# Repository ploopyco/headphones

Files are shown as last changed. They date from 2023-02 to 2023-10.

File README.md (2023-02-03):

# The Ploopy Headphones

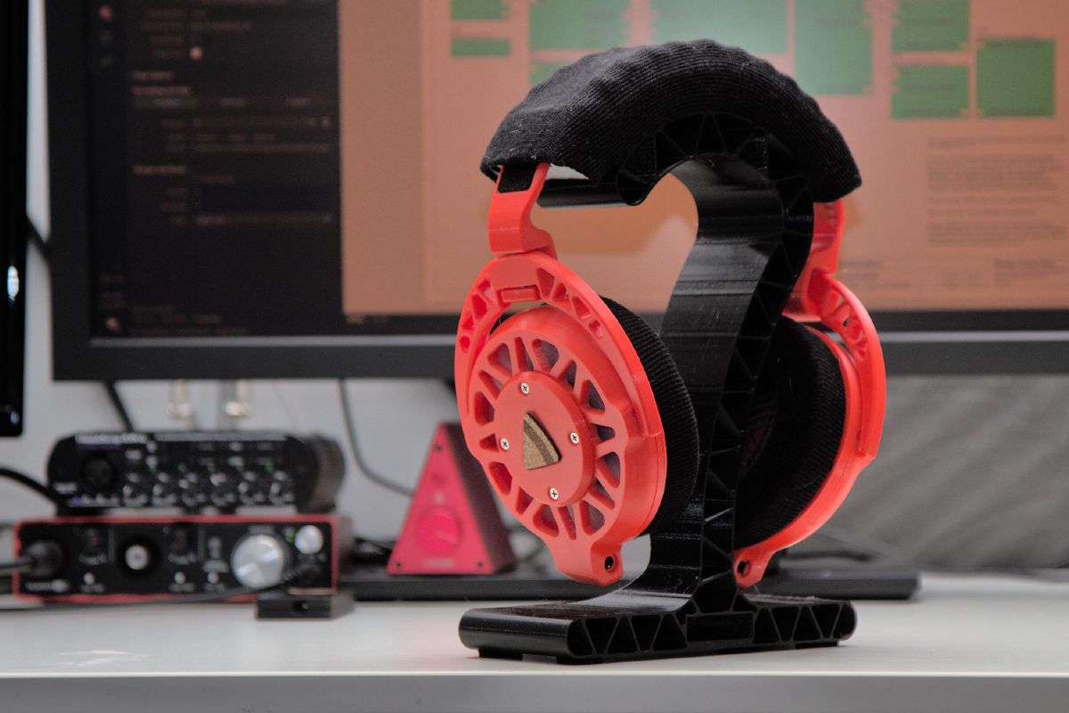
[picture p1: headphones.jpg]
The Ploopy Headphones


By some stroke of luck, you've made your way here. The Ploopy Headphones. Your life will never be the same.

This repository contains all of the design and production files necessary to make a set of Ploopy Headphones. We've also included some kick-ass documentation in the Wiki on how to get it made, assemble it, and program it.

What are you waiting for? Your new life awaits.

## Under what license is this released?

The firmware is released under GPLv3. The hardware is released under OHL CERN v2-S. Check the respective directories for full license text.

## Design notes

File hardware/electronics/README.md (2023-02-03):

"Gould" and "Mazzoleni" are our internal codenames for the boards. You'll also see these names printed on the PCBs, too. These names don't really mean anything; they're just our way of referring to the boards during development, when we don't have release-ready names for things quite yet.

**Gould** -> The Amplifier Board.

**Mazzoleni** -> The Driver Flex Boards.

Simple enough, eh?

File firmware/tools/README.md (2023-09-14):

## filter_test
This is a basic utility for testing the Ploopy headphones filtering routines on a PC.

### Usage
Find a source file and use ffmpeg to convert it to 16bit stereo PCM samples:

```
ffmpeg -i <input file> -vn -f s16le -acodec pcm_s16le input.pcm
```

Run `filter_test` to process the PCM samples. The `filter_test` program takes two arguments an input file and an output file:

```
./filter_test input.pcm output.pcm
```

You can listen to the PCM files using ffplay (which is usually included with ffmpeg):

```
ffplay -f s24le -ar 48000 -ac 2 output.pcm
```

If there are no obvious problems, go ahead and flash your firmware.

## reboot_bootloader.py
If your Ploopy Headphones firmware is new enough, it has support for a USB vendor command that will cause the RP2040 to reboot into the
bootloader. This will enable you to update the firmware without having to remove the case and short the pins on the board.

### Usage
Connect the Ploopy headphones DAC and run:

```
./reboot_bootloader.py
```

You will need python3 and the pyusb module. If you get a permission denied error you may need to configure your udev rules, or run the
script with administrator privileges.

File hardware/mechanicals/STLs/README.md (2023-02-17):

The STLs for the Headphones are packed into a single STL file. This is done for versioning simplicity.

Obviously, the pieces have to be split before they can be printed. Cura and PrusaSlicer both have functionality to split STL files with multiple STLs in them into individual STL pieces. We haven't tested other slicing softwares, and they may also contain this functionality. However, Cura and PrusaSlicer have both been tested and verified as working, and both are available for free.

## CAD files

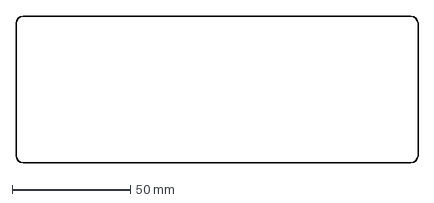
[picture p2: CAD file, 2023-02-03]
hardware/mechanicals/DXFs/HeadbandFoam.DXF
170.0 x 62.0 mm

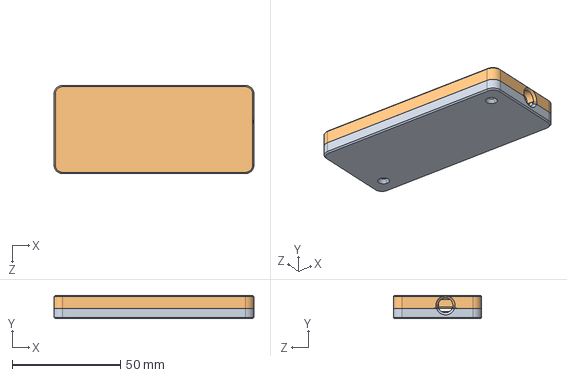
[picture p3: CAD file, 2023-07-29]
hardware/mechanicals/STEPs/DAC-Case-NoLogo.STEP
92.2 x 10.8 x 40.7 mm

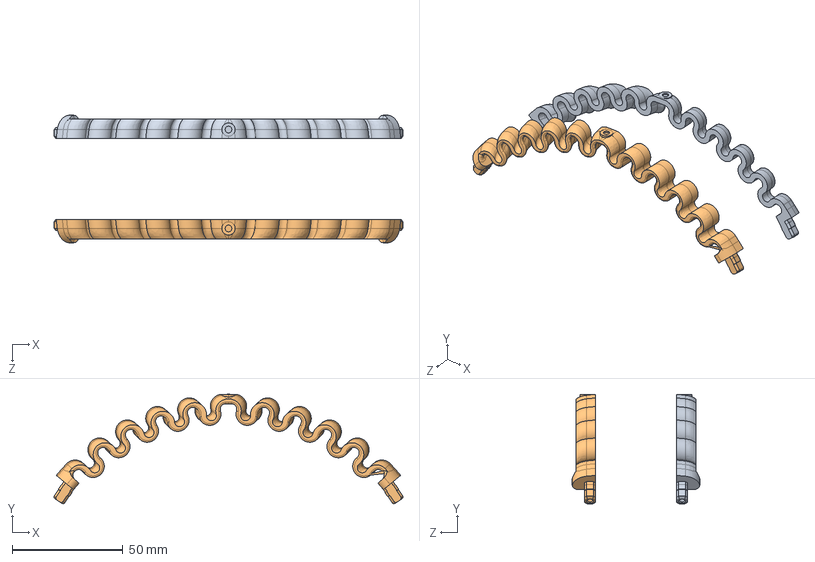
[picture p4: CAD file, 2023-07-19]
hardware/mechanicals/STEPs/Headbands/HPH-038-Headband-Round-LARGE.STEP
157.3 x 49.4 x 57.5 mm

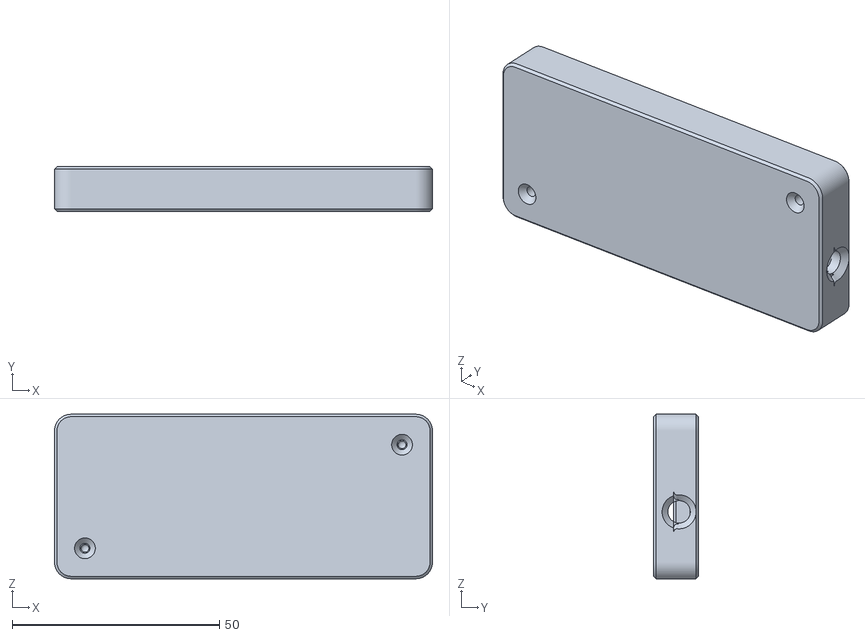
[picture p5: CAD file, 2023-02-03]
hardware/mechanicals/STLs/PloopyPreampCase-RevA.STL
91.2 x 10.8 x 39.7

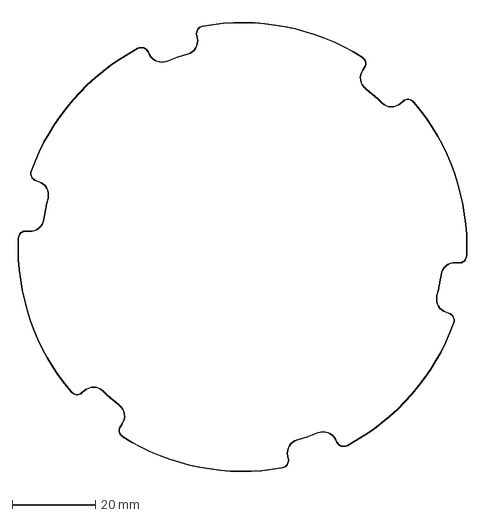
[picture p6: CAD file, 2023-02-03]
hardware/mechanicals/DXFs/Membrane.DXF
109.0 x 111.1 mm

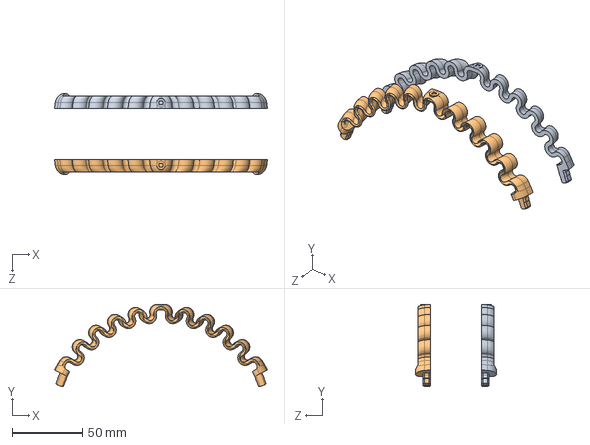
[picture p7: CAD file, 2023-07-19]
hardware/mechanicals/STEPs/Headbands/HPH-040-Headband-Square-MEDIUM.STEP
151.3 x 58.5 x 57.5 mm

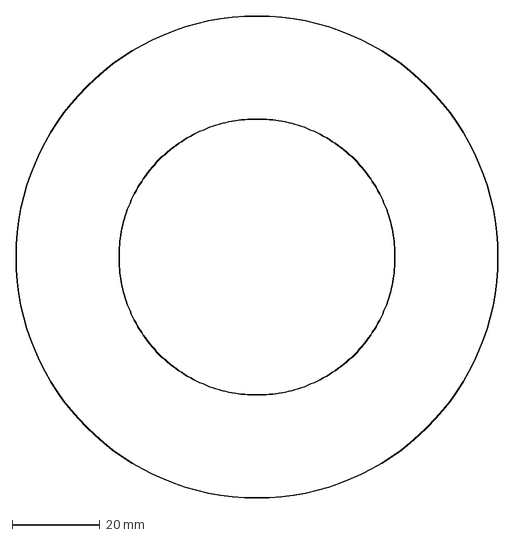
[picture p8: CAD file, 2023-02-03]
hardware/mechanicals/DXFs/Earcup.DXF
110.0 x 110.0 mm

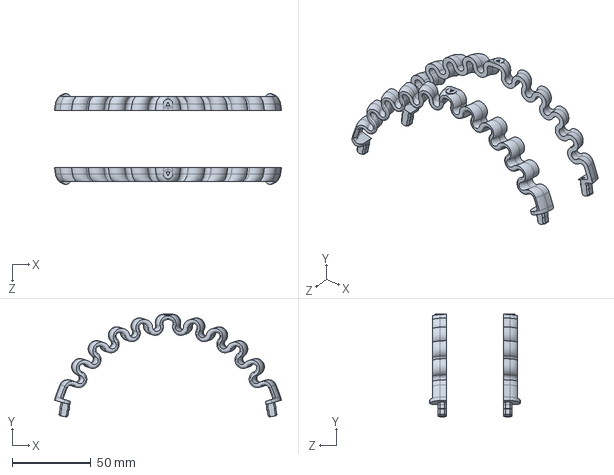
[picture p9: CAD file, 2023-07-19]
hardware/mechanicals/STEPs/Headbands/HPH-041-Headband-Triangle-SMALL.STEP
143.8 x 65.1 x 57.5 mm

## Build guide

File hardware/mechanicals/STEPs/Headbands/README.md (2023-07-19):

There are three sizes of headband, because good things come in threes. The parts can be identified by the mark on the top of the band. For example, the SMALL size of headband has a small triangular mark.

The sizes are relative, and don't correspond to any particular size of head. You might want a small size headband if you have a "small" head, or if you have a "large" head but want a higher clamping force.

For instructions on how to use these headbands, consult the assembly wiki (specifically, Part 4): https://github.com/ploopyco/headphones/wiki/Part-4%3A-Headband

We're always looking for feedback, particularly on ergonomics. If you try all three of these designs and find none of them fit you, please email us at contact@ploopy.co There's a decent chance we can create another size that'll work for you.

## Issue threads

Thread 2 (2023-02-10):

Documentation: Material sourcing improvements

qwertymodo, 2023-02-10:
[Appendix D](https://github.com/ploopyco/headphones/wiki/Appendix-D%3A-Hardware) could use some additional details to properly source materials.

First up, the stockinette only lists a single size, 1.5", but your kits for sale include 2 different sizes, 2" and 3".  So, there's a mismatch there.

Some additional details on the foam would be really helpful, e.g. what kind of material, the density/pressure you use (gives better context to compare against, rather than just "get the lowest possible compression pressure you can find")

Sourcing information for the magnets would be helpful.  I can't seem to find the correct size anywhere.  Even the specialty magnet distributors I've looked at don't seem to carry that exact size.

The rest of the materials seem easy enough to source from the provided information.

megamaniac, 2023-02-10:
I would definitely like to see this as well - for example a 25x5x5 magnet is much easier for me to get hold of. Will this still work in the same way or is 30mm an absolute requirement?

If the dimensional values of the parts can be modified it would be amazing to note this in the descriptions for ease of sourcing.

ploopyco, 2023-02-17:
@qwertymodo I fixed the documentation to include more info about the stockinettes, as well as the foams.

I used Aliexpress to find different magnet sizes and found three vendors supplying magnets in the correct size. Is Aliexpress an option where you are?

@megamaniac The magnet size is not an absolute requirement, of course. The deflection of the PCB is going to change, though, if magnets of different sizes are used.

qwertymodo, 2023-02-17:
AliExpress is definitely an option, and one that I searched before posting here. Unfortunately with things like this it can sometimes be difficult to find exactly what you're looking for, buried in pages of similar items that just slightly aren't correct. Do you happen to have a link to one of those magnet vendors you found?

Closed 2023-07-28.

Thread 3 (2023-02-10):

Option to Purchase Just the PCBs

Wgelyjr, 2023-02-10:
I'd love to manufacture the rest of the parts - it'd be a fun challenge.

I would not like to wrangle a manufacturer into a production run,

I would like to support this awesome project. Mark em up, I don't care, I'll still buy them.

WhosManzIsThis, 2023-02-10:
Agreed,  it would be nice to have an option in between a DIY full kit and sourcing all the parts ourselves.  For example, I happen to have access to 3D printers, but not too many options when it comes to pcb manufacturing, thus having a pre-assembled circuit boards stand-alone purchase option would be ideal.  I really hope the individuals at this company see this thread.

qwertymodo, 2023-02-12:
Bare PCB's only and a "print your own" kit would both be really nice purchase options.  As somebody who has a printer and a lot of really cool filament options, I'd definitely be up for buying a full kit if it didn't feel so wasteful to buy and ship printed parts that I would just throw out.  I was originally thinking of doing a fully self-sourced build, but some of the materials are a bit tricky to find, so a print your own kit would definitely be a good option for people like me.

ploopyco, 2023-02-17:
For the moment, I'm going to continue supplying kits with the 3D-printed parts, only. I do have multiple reasons for sticking with this decision, [which you can read about here](https://blog.ploopy.co/why-we-dont-offer-kits-without-3d-printed-parts-52).

Wgelyjr, 2023-02-18:
I see your reasons, I'm not sure they justify the decision, but it's yours to make. I hope you reconsider at some point, but I bought your kit anyways, and I look forward to receiving it. I appreciate your hard work on this project.

Closed 2023-02-17.

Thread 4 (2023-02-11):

Gerber files

qwertymodo, 2023-02-11:
As far as I can find, Altium doesn't offer any free means of converting their design files into gerbers, would it be possible to include them in the repo?

sirus20x6, 2023-02-14:
to convert altium files into gerbers you have to create an output generator. Then under that output generator file you go to fabrication outputs and you'll want gerber and NC drill files.

qwertymodo, 2023-02-14:
> to convert altium files into gerbers you have to create an output generator. Then under that output generator file you go to fabrication outputs and you'll want gerber and NC drill files.

Yes, but first you have to spend several hundred dollars to purchase Altium. Locking the files behind a proprietary format that has no free way of accessing them isn't really in the spirit of open source.

sirus20x6, 2023-02-14:
I can do it from work tomorrow. I'll also export them as ascii files which
I think can be imported to a few different editors.

On Tue, Feb 14, 2023 at 12:57 PM qwertymodo ***@***.***>
wrote:

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

sirus20x6, 2023-02-15:
[ploopyco.zip](https://github.com/ploopyco/headphones/files/10746818/ploopyco.zip)
Here are the exported gerbers, nc drill files, i also created and included the outjob file and a draftsman file. You'll find exports for ascii versions of the schematics and pcb as well as specctra design, sisoft, p-cad, orcad, ansoft, hyperlynx files.
I've also generated cad files: step, idf, dwg

ploopyco, 2023-02-17:
I believe that KiCAD has an importer for Altium tools.

qwertymodo, 2023-02-17:
I tried a few tools that claimed to support Altium import and they rejected the files because they were not in an ASCII format.

sirus20x6, 2023-02-17:
> I tried a few tools that claimed to support Altium import and they rejected the files because they were not in an ASCII format.

use the zip in my above comment. I have ascii files in there.

Closed 2023-07-28.

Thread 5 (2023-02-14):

unmerge 3d files

sirus20x6, 2023-02-14:
It would really be helpful if every 3d part was in its own file. I'm not sure what we're supposed to do with them all merged together, but I can't give this to my 3d printer

sirus20x6, 2023-02-16:
Been poking at this for a while now. even in the step file everything is fused into one object. you can't actually 3d print it this way.

ploopyco, 2023-02-17:
Cura and PrusaSlicer are two free tools that have both been tested and verified as having the ability to "split" the file into the individual pieces.

As for the STEP file, FreeCAD and Blender are also two free tools that have been tested and verified as having the ability to split the file into the individual components for modification.

sirus20x6, 2023-02-17:
I was unable to split them in either freecad or blender

sirus20x6, 2023-02-17:
I just tried cura. it is unable to split the stl because all the geometry is together under one object. cura is unable to load the stp file

sirus20x6, 2023-02-17:
I just tried prusa slicer as well. it was able to load the stp file, but all the geometry again was under one single object which means it cant be split. it has to be printed as is. in order to print any of these they have to each be their own object which can be done with stp, but is not in this step file.

Closed 2023-02-17.

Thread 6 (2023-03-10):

Is fix16_mul correctly handling the overflow case?

george-norton, 2023-03-10:
I have been browsing the code while I wait for my headphones to arrive, and I can't shake the feeling that something is wrong with the overflow handling here. If I understand right `fix_t` if a 32bit signed value where bit 31 is an overflow bit, bit 30 is the sign bit. This differs from the libfixmath library where there is no separate overflow bit, the sign bit is bit 31. It seems like the shift statement here should be adjusted to shift by 46 bits so the sign bit is included in the test, otherwise if we overflow into the sign bit the overflow will not be detected.

https://github.com/ploopyco/headphones/blob/1771ccab54b087d47403aaec6cd66c3d18addc57/firmware/code/fix16.c#L52

ploopyco, 2023-03-23:
To be perfectly, completely frank, I have no clue. The libfixmath library from which I took the code is not easily decipherable to me. It's entirely possible that you're correct. My only "proof" that I'm right is that the audio sounds right.

If you find that I didn't implement the overflow correction correctly, I'll welcome a pull request.

george-norton, 2023-03-23:
I will have a play when my kit arrives, I wondered if maybe it was the root cause of the audio distortion issues you have been seeing. You seem to have fixed that by reducing the input samples from 16bits to 14bits which could just be making the overflow cases very unlikely or impossible.

I also can't see how the overflow case is handled (although maybe in practice it doesn't happen). It seems like saturating the value would be a good strategy for PCM audio..

george-norton, 2023-03-31:
@ploopyco I have been able to reproduce the audio distortion issue on my PC in a test harness. I have fixed it here:
https://github.com/george-norton/headphones/commit/e6ece89049260f9be8d60c1ed7e397097e602183
But I am reluctant to raise a PR without any real hardware to run it on.

The issue occurs in `bqf_transform` where the value of y can over/underflow causing the sign to flip. With my change `fix16_mul` is allowed to temporarily overflow/underflow as we add and subtract multiple coefficients, the overflow is handled right at the end when we convert back to an `int16_t`.

If you get a chance to test this, and everything works, let me know and I will raise a PR.

george-norton, 2023-03-31:
There is an extra *4 on the volume adjustment in `_as_audio_packet` that might also need to be removed since we are no longer dividing the input samples by 4.

ploopyco, 2023-03-31:
I'll try this on my DAC on Monday. I'm also going to expedite your preorder so that it ships out sooner, so you can try some of this on your own. Really appreciate this sort of contribution; I'll let you know my results on Monday.

ploopyco, 2023-04-03:
It works! Feel free to open a PR, and I'll merge it in.

I've had the privilege of working with some very gifted programmers over my career, but to diagnose and fix a problem at such a low level without actually testing it on the target hardware is one of most incredible feats of engineering I've seen. Well done.

Closed 2023-04-05.

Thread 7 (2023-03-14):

DAC always resampling to 48kHz 16bit

thejevans, 2023-03-14:
I just built my ploopy headphones today. Upon testing, it seems that the DAC always resamples audio to 48kHz 16bit. I made sure to update to the pm5 firmware during testing and the problem still exists. I've tested with sample rates above and below 48kHz and the result is always the same. I tested on multiple linux machines with pipewire and with USB Audio Player Pro on Android.

thejevans, 2023-03-14:
I just noticed the sentence on the product page saying that you all decided to force resampling. Are there downsides to allowing sample rate switching?

ploopyco, 2023-03-23:
The 48kHz/16-bit rate is set by the USB device descriptor [here](https://github.com/ploopyco/headphones/blob/cca0639485fa7383ba7714f32e0514ca87521c97/firmware/code/run.c#L258). So yes, it always downsamples higher bit-rate audio, but that happens before it even gets to the DAC.

The only downside to doing a higher bit rate is that the EQ will have fewer bands. Since all of the EQ is done in the digital domain, a higher bit rate obviously means more bits, and the EQ is primarily limited by processing power. So, more audio quality means less EQ. That's about the only downside (though it's a major one).

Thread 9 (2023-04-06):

Updated firmware binary? 🙏

13tales, 2023-04-06:
Minor issue: could we get an updated compiled firmware?

I'm keen to try out @george-norton's fix to the firmware to see if it has any bearing at all on the USB audio issues affecting recent Macs.

I've tried building it myself, but I'm thinking there may be an issue with my development environment. The resulting noise from 30cm away demonstrated the timeless pedagogical wisdom of the Ploopy firmware-flashing rhyme.

13tales, 2023-04-06:
*Update:* There are definitely problems with my development environment; I've tried building and flashing an earlier commit of the firmware code, with the same result (ie. no sound besides occasional loud screeching.) Would appreciate any insights folks might have on what might be wrong and how to rectify it.

I have some initial issues convincing CMake to find the correct compiler (`arm-none-eabi-gcc`, as specified by the Raspberry Pi Pico PDF), but once I solve those by editing the CMake cache, everything *appears* to work fine; no errors amongst the build output, and I end up with a `ploopy_headphones.uf2` file in my `/build` folder. Flashing it only leads to unpleasant noises and sorrow, however 😬

One discrepancy I've noticed that seems like it might be relevant is that *my* firmware build seems suspiciously larger than either the current binary in `master` or the alpha build you emailed recently. Both of those were ~90kb, whereas mine is coming out at 161kb.

This is the state of VSCode/CMake when I trigger the build (mode: `[Release]`, compiler: `[GCC 10.3.1 arm-none-eabi]`, target: `[all]`)
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

Here's the build output from VS Code:
```
[main] Building folder: pico
[build] Starting build
[proc] Executing command: /opt/homebrew/bin/cmake --build /Users/tom.armstrong/Workspace/pico/build --config Release --target all -j 10 --
[build] [  2%] Creating directories for 'PioasmBuild'
[build] [  2%] Creating directories for 'ELF2UF2Build'
[build] [  3%] Building ASM object pico-sdk/src/rp2_common/boot_stage2/CMakeFiles/bs2_default.dir/compile_time_choice.S.obj
[build] [  5%] No download step for 'ELF2UF2Build'
[build] [  6%] No download step for 'PioasmBuild'
[build] [  7%] No update step for 'ELF2UF2Build'
[build] [ 10%] No update step for 'PioasmBuild'
[build] [ 10%] No patch step for 'ELF2UF2Build'
[build] [ 11%] Linking ASM executable bs2_default.elf
[build] [ 12%] Performing configure step for 'ELF2UF2Build'
[build] [ 13%] No patch step for 'PioasmBuild'
[build] [ 15%] Performing configure step for 'PioasmBuild'
[build] -- Configuring done (0.0s)
[build] loading initial cache file /Users/tom.armstrong/Workspace/pico/build/pico-sdk/src/rp2_common/pico_cyw43_driver/pioasm/tmp/PioasmBuild-cache-Release.cmake
[build] -- Generating done (0.0s)
[build] -- Build files have been written to: /Users/tom.armstrong/Workspace/pico/build/elf2uf2
[build] -- Configuring done (0.0s)
[build] [ 16%] Performing build step for 'ELF2UF2Build'
[build] -- Generating done (0.0s)
[build] -- Build files have been written to: /Users/tom.armstrong/Workspace/pico/build/pioasm
[build] [ 17%] Performing build step for 'PioasmBuild'
[build] [ 17%] Built target bs2_default
[build] [ 18%] Generating bs2_default.bin
[build] [100%] Built target elf2uf2
[build] [ 20%] No install step for 'ELF2UF2Build'
[build] [ 21%] Generating bs2_default_padded_checksummed.S
[build] [ 22%] Completed 'ELF2UF2Build'
[build] [100%] Built target pioasm
[build] [ 22%] Built target ELF2UF2Build
[build] [ 24%] No install step for 'PioasmBuild'
[build] [ 24%] Built target bs2_default_padded_checksummed_asm
[build] [ 25%] Completed 'PioasmBuild'
[build] [ 25%] Built target PioasmBuild
[build] [ 26%] Generating i2s.pio.h
[build] [ 26%] Built target ploopy_headphones_i2s_pio_h
[build] [ 27%] Building C object CMakeFiles/ploopy_headphones.dir/run.c.obj
[build] [ 29%] Building C object CMakeFiles/ploopy_headphones.dir/ringbuf.c.obj
[build] [ 31%] Building C object CMakeFiles/ploopy_headphones.dir/user.c.obj
[build] [ 32%] Building C object CMakeFiles/ploopy_headphones.dir/Users/tom.armstrong/Workspace/pico/pico-sdk/src/rp2_common/hardware_pio/pio.c.obj
[build] [ 34%] Building C object CMakeFiles/ploopy_headphones.dir/fix16.c.obj
[build] [ 34%] Building C object CMakeFiles/ploopy_headphones.dir/i2s.c.obj
[build] [ 35%] Building C object CMakeFiles/ploopy_headphones.dir/Users/tom.armstrong/Workspace/pico/pico-sdk/src/rp2_common/pico_platform/platform.c.obj
[build] [ 36%] Building C object CMakeFiles/ploopy_headphones.dir/bqf.c.obj
[build] [ 37%] Building C object CMakeFiles/ploopy_headphones.dir/Users/tom.armstrong/Workspace/pico/pico-sdk/src/rp2_common/hardware_claim/claim.c.obj
[build] [ 39%] Building C object CMakeFiles/ploopy_headphones.dir/Users/tom.armstrong/Workspace/pico/pico-sdk/src/rp2_common/hardware_sync/sync.c.obj
[build] [ 40%] Building C object CMakeFiles/ploopy_headphones.dir/Users/tom.armstrong/Workspace/pico/pico-sdk/src/rp2_common/hardware_gpio/gpio.c.obj
[build] [ 41%] Building C object CMakeFiles/ploopy_headphones.dir/Users/tom.armstrong/Workspace/pico/pico-sdk/src/rp2_common/hardware_irq/irq.c.obj
[build] [ 43%] Building ASM object CMakeFiles/ploopy_headphones.dir/Users/tom.armstrong/Workspace/pico/pico-sdk/src/rp2_common/hardware_irq/irq_handler_chain.S.obj
[build] [ 44%] Building C object CMakeFiles/ploopy_headphones.dir/Users/tom.armstrong/Workspace/pico/pico-sdk/src/common/pico_sync/sem.c.obj
[build] [ 45%] Building C object CMakeFiles/ploopy_headphones.dir/Users/tom.armstrong/Workspace/pico/pico-sdk/src/common/pico_sync/lock_core.c.obj
[build] [ 46%] Building C object CMakeFiles/ploopy_headphones.dir/Users/tom.armstrong/Workspace/pico/pico-sdk/src/common/pico_sync/mutex.c.obj
[build] [ 48%] Building C object CMakeFiles/ploopy_headphones.dir/Users/tom.armstrong/Workspace/pico/pico-sdk/src/common/pico_sync/critical_section.c.obj
[build] [ 49%] Building C object CMakeFiles/ploopy_headphones.dir/Users/tom.armstrong/Workspace/pico/pico-sdk/src/common/pico_time/time.c.obj
[build] [ 50%] Building C object CMakeFiles/ploopy_headphones.dir/Users/tom.armstrong/Workspace/pico/pico-sdk/src/common/pico_time/timeout_helper.c.obj
[build] [ 51%] Building C object CMakeFiles/ploopy_headphones.dir/Users/tom.armstrong/Workspace/pico/pico-sdk/src/rp2_common/hardware_timer/timer.c.obj
[build] [ 53%] Building C object CMakeFiles/ploopy_headphones.dir/Users/tom.armstrong/Workspace/pico/pico-sdk/src/common/pico_util/datetime.c.obj
[build] [ 54%] Building C object CMakeFiles/ploopy_headphones.dir/Users/tom.armstrong/Workspace/pico/pico-sdk/src/common/pico_util/pheap.c.obj
[build] [ 55%] Building C object CMakeFiles/ploopy_headphones.dir/Users/tom.armstrong/Workspace/pico/pico-sdk/src/common/pico_util/queue.c.obj
[build] [ 56%] Building C object CMakeFiles/ploopy_headphones.dir/Users/tom.armstrong/Workspace/pico/pico-sdk/src/rp2_common/hardware_clocks/clocks.c.obj
[build] [ 58%] Building C object CMakeFiles/ploopy_headphones.dir/Users/tom.armstrong/Workspace/pico/pico-sdk/src/rp2_common/hardware_pll/pll.c.obj
[build] [ 60%] Building C object CMakeFiles/ploopy_headphones.dir/Users/tom.armstrong/Workspace/pico/pico-sdk/src/rp2_common/hardware_watchdog/watchdog.c.obj
[build] [ 60%] Building C object CMakeFiles/ploopy_headphones.dir/Users/tom.armstrong/Workspace/pico/pico-sdk/src/rp2_common/hardware_vreg/vreg.c.obj
[build] [ 62%] Building C object CMakeFiles/ploopy_headphones.dir/Users/tom.armstrong/Workspace/pico/pico-sdk/src/rp2_common/hardware_xosc/xosc.c.obj
[build] [ 63%] Building C object CMakeFiles/ploopy_headphones.dir/Users/tom.armstrong/Workspace/pico/pico-sdk/src/rp2_common/hardware_i2c/i2c.c.obj
[build] [ 64%] Building C object CMakeFiles/ploopy_headphones.dir/Users/tom.armstrong/Workspace/pico/pico-sdk/src/rp2_common/hardware_dma/dma.c.obj
[build] [ 65%] Building C object CMakeFiles/ploopy_headphones.dir/Users/tom.armstrong/Workspace/pico/pico-sdk/src/rp2_common/pico_stdlib/stdlib.c.obj
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
13tales, 2023-04-07:
> I have pushed a simple script here that builds everything inside a simple docker container, it should provide a consistent build environment: https://github.com/george-norton/headphones/tree/docker_build_script/firmware/docker

Thanks! Am I missing something; won't it also need to pull in the Pico SDK and Pico Extras?

13tales, 2023-04-07:
@george-norton Very nice! It worked, thanks.

I did find it was necessary to add `RUN git config --global --add safe.directory "*"` to the Dockerfile, or I received an error along the lines of `"fatal: detected dubious ownership in repository"` from Git when it was attempting to fetch the Pico SDK.

Still very curious about why my attempting to build with VS Code was apparently succeeding, but resulting in those broken oversized binaries 🤔

13tales, 2023-04-07:
It's too early to say conclusively whether the firmware change reduces the Mac M1-related USB audio issues.
I've definitely noticed some occurrences of it since flashing the new firmware just now, but it seems like it *might* possibly have reduced the frequency and severity?
Memory consumption seems to be a cause of the issue, and I'm not working today, so don't have quite my usual burden of docker containers, nodeJS processes, and browser tabs open and competing for resources.

It seems plausible that power consumption might be a factor, based on Colin's speculation, and my testing with the only other USB audio device that I have around (the dongle for a Logitech gaming headset, which *doesn't* suffer from the issue). Is this update likely to have reduced the power draw of the Ploopy DAC at all?

13tales, 2023-04-13:
I had a poke around in the MacOS audio settings; both devices accept 16bit 48khz.
I think this is a low-level issue with MacOS and the M1 hardware in particular; the older and *less*-powerful Intel machines don't seem to suffer from it. [Here's one of many threads on the issue](https://developer.apple.com/forums/thread/677383?page=2), if you're interested.

Firmware programming and USB audio are well outside my realm of competence, so I'm not sure what to look for re: audio clocking. I've done my best to inspect both devices using some of the MacOS utilities and try and figure out what's different. The only thing I've spotted so far is that the `bMaxPacketSize0` property differs between them; it's `0x40` for the Ploopy DAC, `0x10` for the Logitech. No idea whether that could be a factor.

The underlying issue obviously rests with Apple, but I am curious if there's a workaround possible within the Ploopy firmware.

I've tried meddling with the ring buffer size within the Ploopy firmware, doubling it to 64kb—I only use these to listen to music, so I don't really care about latency—but it doesn't fix the issue. It *might* have decreased its frequency, but without measurements to back that up, I think it's probably the placebo effect on my part.

george-norton, 2023-04-13:
@ploopyco The docker build script is a bit quick and dirty, but it works and it should ensure everyone produces identical binaries when they checkout a particular revision of the code. Potentially you could also push prebuilt images to some docker repository and speed up the build process.
Once you have had a play with it, let me know if you are still interested in a PR.

13tales, 2023-04-13:
> @13tales I'll update the repo with an updated firmware. I've been lazy with it, but I'll get it done.

@ploopyco I'm happily building away with the Docker script now, but much appreciated, thanks 🙏 Feel free to close this issue.

I doubt I'm the only person who's going to run into the irritating MacOS/M1 issue, and I'm holding out hope that a Mac user who knows what they're doing might be able to figure out a firmware-side workaround for it. Might create another issue thread as a home for discussion about it, if that's okay by you.

ploopyco, 2023-04-14:
> Might create another issue thread as a home for discussion about it, if that's okay by you.

Fine with me.

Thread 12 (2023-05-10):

Left and right channels reversed

mrlinuxfish, 2023-05-10:
The audio output for the left channel is being sent to the right ear cup and vice verses.

Looking at the driver boards, the tip is only connected on the right side and the ring is only connected on the left side. According to convention, the tip is for left / mono audio and the ring is for the right channel.

A workaround can be wearing the headphones backwards, but it is much more elegant to have the cable come out of the correct side of the headphones (this will also reduce strain on the cables)

ploopyco, 2023-10-16:
I'm guessing we've talked about this on Discord/Reddit since, so I'll just close this issue with some notes for future readers:

As of this writing, the headphone drivers are wired *backwards* -- the left driver is connected to the canonically right channel of the TRS jack and vice versa. This is due to the fact that the supplier for our TRS splitter cable secretly reversed the connections, and we didn't think to check beyond verifying that the correct sound came from the correct side.

If you're using a custom cable, you can use the [headphones toolbox](https://github.com/ploopyco/headphones-toolbox/releases) to flip the channels of the output signal.

Closed 2023-10-16.

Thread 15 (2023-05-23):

Firmware PM8 Requires reflash with every unplug

keeb-time, 2023-05-23:
Flashed firmware pm8 and followed the readme. Flashing the firmware works and the amp immediately reboots and is usable. The amp contiues to work great until it gets unplugged. Upon plugging the amp back in it isnt recognized by the system until the firmware is flashed again, then it works great until unplugged and replugged again. I'm unsure why this is as pm7 worked fine. Computer is running windows 11.

ploopyco, 2023-05-25:
Crap. Yes, this is confirmed. It's also an issue with all builds of the pm9 release.

@george-norton Do you have any ideas? I can debug and fix this issue, but I can only start on it by next Wednesday.

george-norton, 2023-05-25:
Does this happen with other operating systems or just Windows 11 (how about windows 10?)? I have been running my own builds which should be equivalent to pm8 and pm9 and I haven't seen any issues, but I don't use Windows all that much.

george-norton, 2023-05-25:
I tried the pm9 binary with my Windows 10 laptop and I wasn't able to reproduce the issue. Not sure what the cause may be, nothing jumps out when looking at the code again.

Could it be some effect due to the increased I2C clock speed?

ploopyco, 2023-05-25:
Hm. It's possible. The DAC not working after it's been unplugged and plugged back in means that the flash memory isn't being successfully accessed. I know that increasing the SPI bus speed causes this problem, but that's because the MCU and the flash chip communicate via SPI. So, increasing the I2C clock speed shouldn't affect that, but it might be affecting something else.

If you can't reproduce the issue, I'll tackle this.

george-norton, 2023-05-25:
It seems more likely that either the ARM core is taking a fault, or the usb stack is stalling the control endpoint due to some error. I don't have a Windows 11 system - are you able to reproduce the issue on a different OS?

keeb-time, 2023-05-26:
I can see if it works on my work mac, testing in a few here.

keeb-time, 2023-05-26:
Can confirm that the problem is the same on my mac, finder even reports that the disc doesnt eject properly. After a plug and replug, the system doesnt see it. This was attempted with pm9.

ploopyco, 2023-05-31:
Okay...strangest thing. I can't reproduce the issue anymore. On two separate computers, across multiple boards.

@keeb-time, can you try deleting the USB descriptors from your Windows machine and trying again? If that doesn't help, I...honestly have no idea what we're going to do, actually.

george-norton, 2023-05-31:
Maybe we could prepare a test build with the I2c clock reverted to 50khz to see if that fixes it for @keeb-time ?

ploopyco, 2023-06-02:
[Got a test build live here](https://github.com/ploopyco/headphones/blob/ploopyco/keeb-time-test/ploopy_headphones-master-50k.uf2). @keeb-time, let me know if it makes a difference.

keeb-time, 2023-06-03:
Thanks for the test build, just flashed it from my windows computer and it rebooted straight into being a sound output device. I think this is good :)

I'll test on my work mac tomorrow, but I'm betting it works there too

keeb-time, 2023-06-06:
is there anything I can do to assist? is there a way to put the amplifier in a debug mode and capture the output?

george-norton, 2023-06-06:
Unfortunately the DAC doesn't have an easily accessible serial port or debug interface, they are on test points rather than a through hole debug header so they are awkward to access without additional hardware. I don't know about logs on Windows, but if you connect to your Mac then run 'dmesg' you should see a few log messages from MacOS. But I suspect there won't be anything too helpful.

Other than that, if you can spare some time, perhaps we can start doing a binary chop on the changes to see what works and what doesn't. I.e. I could produce a firmware image that contains around half the changes that went into pm8, and we can narrow down the problem that way..

keeb-time, 2023-06-06:
Presently Upon booting with the amp plugged in pre-flash:
https://pastebin.com/MafjaPTQ

dmesg after reset and flash:
[  720.640404] usb 3-7: new full-speed USB device number 6 using xhci_hcd
[  720.768229] usb 3-7: New USB device found, idVendor=2e8a, idProduct=0003, bcdDevice= 1.00
[  720.768243] usb 3-7: New USB device strings: Mfr=1, Product=2, SerialNumber=3
[  720.768246] usb 3-7: Product: RP2 Boot
[  720.768249] usb 3-7: Manufacturer: Raspberry Pi
[  720.768252] usb 3-7: SerialNumber: E0C9125B0D9B
[  720.773601] usb-storage 3-7:1.0: USB Mass Storage device detected
[  720.774295] scsi host1: usb-storage 3-7:1.0
[  721.778230] scsi 1:0:0:0: Direct-Access     RPI      RP2              3    PQ: 0 ANSI: 2
[  721.778987] sd 1:0:0:0: Attached scsi generic sg1 type 0
[  721.780196] sd 1:0:0:0: [sdb] 262144 512-byte logical blocks: (134 MB/128 MiB)
[  721.780762] sd 1:0:0:0: [sdb] Write Protect is off
[  721.780772] sd 1:0:0:0: [sdb] Mode Sense: 03 00 00 00
[  721.781383] sd 1:0:0:0: [sdb] No Caching mode page found
[  721.781391] sd 1:0:0:0: [sdb] Assuming drive cache: write through
[  721.788388]  sdb: sdb1
[  721.788760] sd 1:0:0:0: [sdb] Attached SCSI removable disk
[  731.014677] usb 3-7: USB disconnect, device number 6
[  731.015609] device offline error, dev sdb, sector 260 op 0x1:(WRITE) flags 0x100000 phys_seg 1 prio class 2
[  731.015627] Buffer I/O error on dev sdb1, logical block 259, lost async page write
[  731.038610] FAT-fs (sdb1): unable to read boot sector to mark fs as dirty
[  732.169028] usb 3-7: new full-speed USB device number 7 using xhci_hcd
[  732.296451] usb 3-7: New USB device found, idVendor=2e8a, idProduct=fedd, bcdDevice= 2.00
[  732.296463] usb 3-7: New USB device strings: Mfr=1, Product=2, SerialNumber=3
[  732.296468] usb 3-7: Product: Ploopy Headphones
[  732.296471] usb 3-7: Manufacturer: Ploopy Corporation
[  732.296473] usb 3-7: SerialNumber: 000000000001
[  732.351939] usbcore: registered new interface driver snd-usb-audio

Now, I will unplug and replug:
[  833.620774] usb 3-7: USB disconnect, device number 7

that is the only thing that changes, it never re-recognizes the device after the replug. This might be an issue with starting up the usb controller?

I did all this from my windows laptop running a fedora live image, let me know if there's any more information you need. I want this to work right not just for me but for anyone else that runs into this.

ploopyco, 2023-06-12:
@keeb-time Out of curiosity, what happens if you try George's [headphones toolbox build](https://github.com/george-norton/headphones-toolbox)?

keeb-time, 2023-06-18:
Sorry about the delay, work was super busy and I needed a day. I just attempted with that build and can say that it still needs to be reflashed each time I plug it back in in order to stay working. For the record I have an early unit and am flashing it by shorting the two reset pads and then dragging and dropping the file onto it when it shows up as a drive.

keeb-time, 2023-06-18:
Just tried playing with the toolbox software and even using it to tell the amp to reboot into bootloader and then load the files it still doesnt persist through a reboot. Perhaps my unit has bad flash?
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
keeb-time, 2023-06-21:
I've flashed the new version that you made and I can tentatively say that it works. It's survived three unplugs so far. I'm tempted to put the case back on.

keeb-time, 2023-06-21:
And now its back to not starting up properly...not sure why it seems intermittent

keeb-time, 2023-06-23:
Sorry for the multiple comments here, I'd say that whatever you did is an improvement enough that the amp is usable so long as I plug and unplug it enough times. Something is still off but it's an improvement over how it was. I'm curious as to why the firmware's prior to this one work every time. I'm new to the dev world and this has been a good learning experience so far

Roosta078, 2023-06-29:
This seems like the same bug I have experienced and fixed in my [PR](https://github.com/george-norton/headphones/pull/1) from yesterday.  This change completely fixed the issue for me.  To summarize, the SPI flash speed was getting set out of spec for the flash chip.  Perhaps the higher clock speed was fine on some silicon, but not on others.  @keeb-time could you try out that version?

keeb-time, 2023-06-29:
I should be able to flash that later tonight, looking forward to seeing how it goes!

george-norton, 2023-06-30:
Thanks @Roosta078, I am on vacation this week, I will take a look next week. I noticed the Pico SDK introduced some new functionality for adjusting the peripheral clocks when the system clock changes. See 'PLL and Clocks' in the release notes here https://github.com/raspberrypi/pico-sdk/releases. We just take the current master of the Pico SDK repo, so it is possible something changed in the SDK between the pm7 and pm8 builds, not sure. Also it is possible enabling this new feature might help. I don't quite understand why this stuff might have changed between pm7 and pm8 as I didn't mess with the system clock of QSPI clock.

Roosta078, 2023-06-30:
I worry that PM7 and earlier were not built with a clean pico-sdk.  I checked on the old images, and as described above pm7 worked with unplug/replug.  pm8 did not.  I then built from pm7 [commit](https://github.com/ploopyco/headphones/commit/a8f9b522deec4178ad5c6dff4652531edfa1c6d4) and replugging no longer worked.  I then went and reverted my pico-sdk and pico-extras to the lastest commits as of pm7 and replugging still did not work.  My theory is that there may have been local modifications to ploopyco's sdk and that at some point between pm7 and pm8 they pulled the latest version.

george-norton, 2023-06-30:
If you use the download SDK environment variable, the SDK is downloaded once, but never updated when you rebuild. So potentially the pm7 image is built against a fairly old SDK checkout.

Probably we should build against officially tagged SDK releases rather than just using the master branch at the time you happened to do your first build, that would at least give us reproducible builds.

keeb-time, 2023-06-30:
@Roosta078 I didn't see a build to download and try when I looked the other night, do you have one available?

Roosta078, 2023-07-03:
> @Roosta078 I didn't see a build to download and try when I looked the other night, do you have one available?

Yes, and sorry for the delay, Github did not send a notification.  I uploaded a build to the [PR](https://github.com/george-norton/headphones/pull/1#issuecomment-1618881608). Let me know how it goes.

keeb-time, 2023-07-04:
Your build is a winner! I have not had to reflash since and the amp comes up everytime I plug it in! Thank you :)

Roosta078, 2023-07-04:
I later noted in the PR that another change that resolved the issue was increasing the PICO_XOSC_STARTUP_DELAY_MULTIPLIER and leaving the SPI clock as is.  This may be the preferred solution, but I figured I would open it up to discussion.

Roosta078, 2023-07-04:
I later noted in the PR that another change that resolved the issue was increasing the PICO_XOSC_STARTUP_DELAY_MULTIPLIER and leaving the SPI clock as is.  This may be the preferred solution, but I figured I would open it up to discussion.

george-norton, 2023-07-04:
It sounds like that would be preferable, but I would be interested to know what @ploopyco think.

ploopyco, 2023-07-13:
Changing PICO_FLASH_SPI_CLKDIV is not preferable. While doing the original dev work, I'd found that reading from flash was unreliable at PICO_FLASH_SPI_CLKDIV values other than 2. I suspect the reason why is that the RP2040 is significantly overclocked, resulting in SPI speeds that are slightly different between actual chips.

I hadn't experimented with PICO_XOSC_STARTUP_DELAY_MULTIPLIER during dev. If it works, I'd go with that.

I'll also paste this comment into the PR.

Closed 2023-08-23.

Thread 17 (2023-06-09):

Documentation: Part 2 Drivers; minor error

cycletronic, 2023-06-09:
There is text that says:
"See the photo, as well as the photo in Step 4, for clarification."

The photo for step 4 is unhelpful for clarification.  I believe the intent is to point to the photo for either step 3 or step 5.

ploopyco, 2023-06-12:
Yes, you're right! Corrected. Thanks for pointing this out!

Closed 2023-06-12.

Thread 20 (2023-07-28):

DAC loses connection every ~15minutes

ploopyco, 2023-07-28:
We have a user report of the DAC disconnecting from the PC.

Some notes:
- Windows PC, USB A to C cable shipped with kit used.
- USB port is on a desktop, attached to the front port panel.
- Disconnects happen on average every 15 minutes.
- Issue can be remedied reliably by unplugging the DAC and plugging it back in.
- No notable errors on the Windows side (pop-ups or whatnot).
- Seems to work better with a C to C USB cable, but testing is still in progress on that front.

randomlongname, 2023-10-26:
I am having the same problem with the headphones I just finished assembling yesterday (10/25/23).
I have found the more I play the more frequent it resets, to the point it resets immediately.
It does not reset with only one head phone attached.
Most importantly if I turn the volume down one notch from max the problem goes away completely. :)

qoh, 2023-10-30:
I find that this is strongly correlated with volume. I can reliably reproduce it by setting my OS volume level above 87% (-3.63 dB) and playing [Cleaning Apartment - Clint Mansell on Spotify](https://open.spotify.com/track/3nHWJEJlL1wUvvsQG7UTat), and waiting for the 00:04 low frequency "thunk" hit. That is, if I do this with a volume level of 88% (-3.33) dB, then the DAC disconnects at 00:04.

- Firmware PM16, default configuration
- Spotify volume = 100%; streaming quality = Very high; auto adjust quality = Off
- PipeWire PulseAudio on Linux

Future testing suggestion: Try it with a public raw audio file.

Other anecdata:
- I've also encountered this while raising Headphones Toolbox EQ curves higher
- It also occurs for me with a Pixel 6 Pro running Android 14

It's almost like an overflowing sample value is causing NaNs/infinities that brick the chain until a reset.

qoh, 2023-11-02:
A few more observations:

It is not on the input side: Lowering Pre-EQ Gain from -4.1 dB to -8 dB lets me crank OS volume to 100% without reset.

It is not in the filtering: Raising Post-EQ Gain from +3 dB to +6 dB causes it to reset there even at 87%.

In other words, in my experience, the DAC disconnects when a sample is too loud somewhere after the Post-EQ Gain step; its value does not matter anywhere before that.

ploopyco, 2024-04-07:
The root cause of this problem appears to be too much power draw resulting in the upstream USB host cutting power to the device. Reducing power draw by lowering the volume is a possible fix (though not ideal). Finding a USB power with higher power capacity (or no overcurrent protections) is another. Closing for now; if you're still having problems, please email us at contact@ploopy.co

Closed 2024-04-07.

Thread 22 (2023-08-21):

Headband Sliders In Kit Different From Wiki

maxcaplan, 2023-08-21:
The 3d printed headband slider pieces that came with my kit are different from the ones pictured in the assembly wiki on Github. I don't understand how the driver holders can be inserted into the headband sliders with the metal pins.

Images to show differences between the pieces: [https://imgur.com/a/lO0dYWh](https://imgur.com/a/lO0dYWh)

ploopyco, 2023-10-16:
I believe we already talked elsewhere; if not, please contact us at contact@ploopy.co

For others' future reference, we don't monitor Github issues regularly. For product support, please use email (see above).

Closed 2023-10-16.

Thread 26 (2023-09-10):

Ready to manufacture gbr files

onidev, 2023-09-10:
Hello,

It is possible to release ready to manufacture files for pcbway/jlcpcb?
I don't have Altium and was not able to use/import files from here: https://github.com/ploopyco/headphones/issues/4

I assume they expect .gbr / .dlr files. For reference, I was able to make this PCB with jlcpcb:
https://github.com/Redherring32/OpenTendo
The release is ready to manufacture, and there are clear instructions on the main page (recommended PCB specs).

Thank you

ploopyco, 2023-10-16:
Unfortunately, we can't act as the interface between you and your board house.

Closed 2023-10-16.

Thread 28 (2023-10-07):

Add headphone jack audio input option

Renha, 2023-10-07:
While it is understandable to want to use single interface for both audio and charging, this limits the use cases of the headphones. For example, for delayless audio monitoring during the recording my microphone requires audio jack capable headphones.

ploopyco, 2023-10-16:
The DAC we use (PCM3060) has an ADC for this purpose, but the board as designed lacks an input connector and suitable pre-amp. As much as we wanted to, every design is an exercise in compromise, and we figured more of our users would want these headphones for listening than for live audio applications.

That said, the project is open source, and I'd be delighted to see a modified version of the PCB that has the requisite hardware to enable it. Closing in anticipation of a pull request. ❤️‍🔥

RustoMCSpit, 2023-10-29:
> That said, the project is open source, and I'd be delighted to see a modified version of the PCB that has the requisite hardware to enable it. Closing in anticipation of a pull request. ❤️‍🔥

could this be mentioned on the website that the project is looking for someone to PR this? even in the readme would be great.

Closed 2023-10-16.

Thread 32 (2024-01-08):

Headphones disconnecting

doomguy-47, 2024-01-08:
Occasionally my headphones will not output any sound and you can't change the volume. It won't move when you press the buttons and if you use the slider it will just go back once you close the window.  Youtube displays an error saying that the audio drivers are invalid or something like that.

It is fixed by temporarily unplugging the DAC and plugging it back in and with a windows restart.

I've already updated windows and checked drivers in device manager and it hasn't fixed it. My DAC is double sided taped to the bottom of my desk but does not feel hot. It might be caused from launching a game but I'm not sure since I turn on a game after my computer has been on for a while.

I've look at another issue linked [here ](https://github.com/ploopyco/headphones/issues/20) about some ones headphones not working after a section in a song but I could not repeat it. My DAC is double sided taped to the bottom of my desk but does not feel too hot.

ploopyco, 2024-04-07:
We're finding that the DAC draws too much power for some USB ports, which can result in the upstream host cutting power. The best thing to do in this case is 1) turn the volume down or 2) find a port with a higher power capability (powered hubs tend to be pretty good bets in this regard).

If you need further support, please email contact@ploopy.co

Closed 2024-04-07.

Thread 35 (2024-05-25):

question What are the plans for adding ANC to the headphones?

Jaron123, 2024-05-25:
On the Element14 interview I read there were plans for implementing noise-cancellation features and self-calibration.
I'd be very interested in an opensource ANC implementation myself and would love to contribute if possible.

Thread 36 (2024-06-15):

Install instructions "triangle" strength not mentioned

schneems, 2024-06-15:
In https://github.com/ploopyco/headphones/wiki/Part-4%3A-Headband it talks about a circle and square headband with different tension properties. There's also now a triangle headband that came with my kit. It seems like the difference is the curvature of the headbands. If that's true I'm guessing that it's now:

- Circle: Weakest
- Square: Medium
- Triangle: Strongest

Can you verify that's correct and update the wiki?

shadow-absorber, 2025-02-02:
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

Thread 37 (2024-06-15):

Install instructions pedagogy

schneems, 2024-06-15:
## Current instruction pedagogy

The format of the install instructions is currently

- Header with a command i.e. "Apply a strip of tape to one of the Driver Flex Boards"
- Picture
- Bullet point of very important caveats that might be below the fold of the picture

## Suggested instruction pedagogy

I am suggesting a change to the format and order of instructions

- Header numbered or labeled without a verb or command i.e. "Heandband Step 4" or "Step 4" or "Section 2, Step 4" or "Step 2.4"

Why? The current instructions require me to read a command and then exercise executive function to not act on it immediately. It sounds minor, but if there's an order we want the user to follow i.e. "read all instructions, then follow command" then the user will have more success if the instructions are given in that order. Removing the "command" from the step name is progress towards that goal.

- Bullet point of very important caveats without any verbs

Why? This structure presents the user with what we want them to do before they take an action. I would also possibly suggest sub-dividing "really important" caveats into "verification" actions instead of being caveats.

This also moves the picture below the caveats because today it's common to have the caveats hidden by accident when following directions, for example:

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

- Picture

Why? Move picture so it doesn't hide the caveats

- Command with explicit marker such as an emoji like ➡️ or since the ploopy logo looks like a pizza it could be 🍕

Why? Make commands as explicit as possible. Use consistency and visual markers to differentiate commands from other writing. I'm on the fence for if I think this should be before or after the picture i.e. grouped with the other writing or by itself. The upside of putting it after the picture is it's more likely to be identified as a command. The downside is someone might scroll so the picture and command are only visible and make it harder to reference the caveats.

## Other miscellaneous suggestions

The above doesn't really require any rewording, just re-ordering so I think it's not a huge change. One other suggestion is pulled from some advice I wrote a long time ago https://www.schneems.com/post/60359275700/prepare-do-test-make-your-technical-writing-shine which is to include "test" instructions.

I had an awful time with the magnets, that section has a lot of disclaimers

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

It's hard for the user to keep multiple pieces of information in their head. These many caveats could be broken into some "verification" steps. I would start with the last one. Instead of

> each magnet should fit tightly into the Driver Cap. If it doesn't fit snugly, try wrapping a single piece of tape around the magnet and insert it again.

You could say:

- 💡 If the magnets are not tight in the cap they might "shoot" out or otherwise be difficult to install
- 🍕 Check that the magnets fit snugly in the cap by taking one magnet and inserting it in the cap as shown in the picture
- ✅ If the magnet is loose or falls out, wrap a single piece of tape around the magnet.
- 🔁 Check that the magnet is now snug. If not, add more tape 🔁 . Use this same process on any future magnets that are not snug.

It's more work and words but it does a few things. The 💡 is giving the background context of why this is important, then the check is turned into an action item in 🍕. Then the ✅  becomes a verification step. For anyone who's magnets were snug, great they can skip to the next section, but now everyone has for sure done a test fit and is aware that there's a mitigation available if a future magnet doesn't fit.

Anyway, I love the idea of open hardware and I spend a lot of time writing software tutorials. The existing tutorials are already good, I wanted to share my experience of how I think we could make them better. Thanks for putting all this together!

ploopyco, 2024-06-17:
This is actually great advice. We're reworking all of our documentation, and I'm going to be referring to this when I'm doing it. Thanks for putting this all together!

schneems, 2024-06-17:
Thanks again for the docs, and validating my feedback. You're welcome to close the issue and reference it (or keep it open if you want until the re-write is done).

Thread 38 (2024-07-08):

Youtube error from headphones

schneems, 2024-07-08:
This is going to sound weird, but the headphones managed to make youtube inoperable for me. I kept getting this message

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

At first I only caught the "please restart your computer," to which I was a little offended. Since when has a problem with chrome required a computer restart? It showed up on every youtube page. Even after I shut the browser down and restarted it.

On second look, I realized it's saying I had a problem with the audio. I unplugged my ploopy headphones, refreshed the page and sure enough...it worked.

I'm not sure how to reproduce the issue. I've played plenty of youtube videos with the headphones. Maybe there's a time/heat issue or something? I recently switched to a shorter USB c cable (3-feet) and it's plugged into a thunderbolt dock to power the ploopy. The cable is laptop charging rated. I'll keep an eye out if I think other factors might affect it.

shadow-absorber, 2025-02-02:
yeah can confirm this.... if you let the ploopy headphones not output audio for a while youtube starts failing to playback sound and so does twitch or other apps on linux too...

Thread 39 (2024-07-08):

[Feature Investigation] Different magnet alignment: Halbach Array

schneems, 2024-07-08:
Someone suggested a different magnet alignment for stronger magnetic field. I suggested they open an issue, but didn't so here I am. Context https://www.reddit.com/r/ploopy/comments/1dr42ay/halbach_array_for_headphones/.

The idea is that by changing how the magnets are aligned, it could make the headphones stronger. I didn't have a chance to try it out. I'm curious if it's a known bad idea because of **reasons** and if it's been tried or not.

Can someone try this out and report back? I'm swamped at the moment, but I'm interested in learning more.

cab404, 2024-08-13:
I've slapped together a model allowing you to put 7 magnets in for a proper Halbach Array.
https://github.com/cab404/ploopy-mods/blob/master/newcap/experiments/hallbachcap.stl

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

Should be printable.
IDK, maybe print it and compare to baseline?

cab404, 2024-08-20:
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
something-something you will require 13x 3x3x30 brick/cylindrical magnets

schneems, 2024-11-18:
I got a bit distracted in my quest for louder jams.

I found https://github.com/cab404/ploopy-mods/tree/736a983d29a48fdbb119229f41d20266aa45e459/newcap from the Subreddit some time ago but haven't gotten around to trying any of them. Seems that it "simply" moves the magnets closer to the driver which increases the volume. It requires modifying the headphones though:

> You'll need to remove several perimeters (0.5mm) from the sides of driver frames, so the cap can with with magnets.

(And just noticed that @cab404 made that! Thanks! 👋 )

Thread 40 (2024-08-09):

rp2040 driver replacement

epsi1on, 2024-08-09:
Hi,
Thank for sharing great project.
I had a question about the rp2040 DAC and amplifier. Is it possible to use other headphone amplifiers in the market instead of the kit's original driver? How much decrease in quality will i get?
i mean a driver like this one which i've found by google:
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

The original pico PCB is somehow hard to solder for an electronic noob like me (because of the small parts, and accessories which i do not have).

Cheers

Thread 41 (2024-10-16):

Confirm where firmware code is living

unawarez, 2024-10-16:
I've seen references on different pages, most recently https://github.com/ploopyco/headphones/blob/master/firmware/README.md saying not to use the firmware here, only use firmware in the george-norton fork. But, looking at GitHub release times and file timestamps, this repo's releases are still newer. Could someone confirm the current status, and possibly fix at least that README?

I'm having USB-related problems and thought I might as well look at the code, but this has been confusing. Thanks!

shadow-absorber, 2025-02-02:
agree that this needs some clarification

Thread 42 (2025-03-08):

Amplifier doesn't do anything. The headphones are incredibly quiet.

cray12399, 2025-03-08:
I finished building my Ploopy headphones this morning. The build went well and everything appears to be fine mechanically. I made sure the drivers were centered as shown in the guide and the magnets are all aligned properly as well using the method shown in the video. I flashed the amplifer by dragging the most recent firmware onto the amp when it was in bootloader mode.

Despite all this however, the headphones are unusably quiet. Even when I have over-amplification enabled on my PC, they dont get anywhere near the volume of my Audio Technica's and I can barely hear the music. To verify whether it is the microphone or the headphones, I plugged the headphones directly into my PC. They sounded exactly the same as plugged into the amp, which leads me to believe the amp is not doing anything.

I have tried flashing the amp multiple times to no avail. Of note, the amp gets pretty warm while plugged in, and the ploopy headphones toolbox is unable to recognize it when plugged in. My PC does, however, identify the amp as "Ploopy Headphones."

Can I get some assistance on this issue?

cray12399, 2025-03-08:
I actually plugged the headphones directly into my PC's sound card and they are definitely approaching usable with the volume, but there's a lot of distortion. I imagine because I don't have the right EQ preset. I also don't want this to be a long term solution since I use my sound card for my speaker system.

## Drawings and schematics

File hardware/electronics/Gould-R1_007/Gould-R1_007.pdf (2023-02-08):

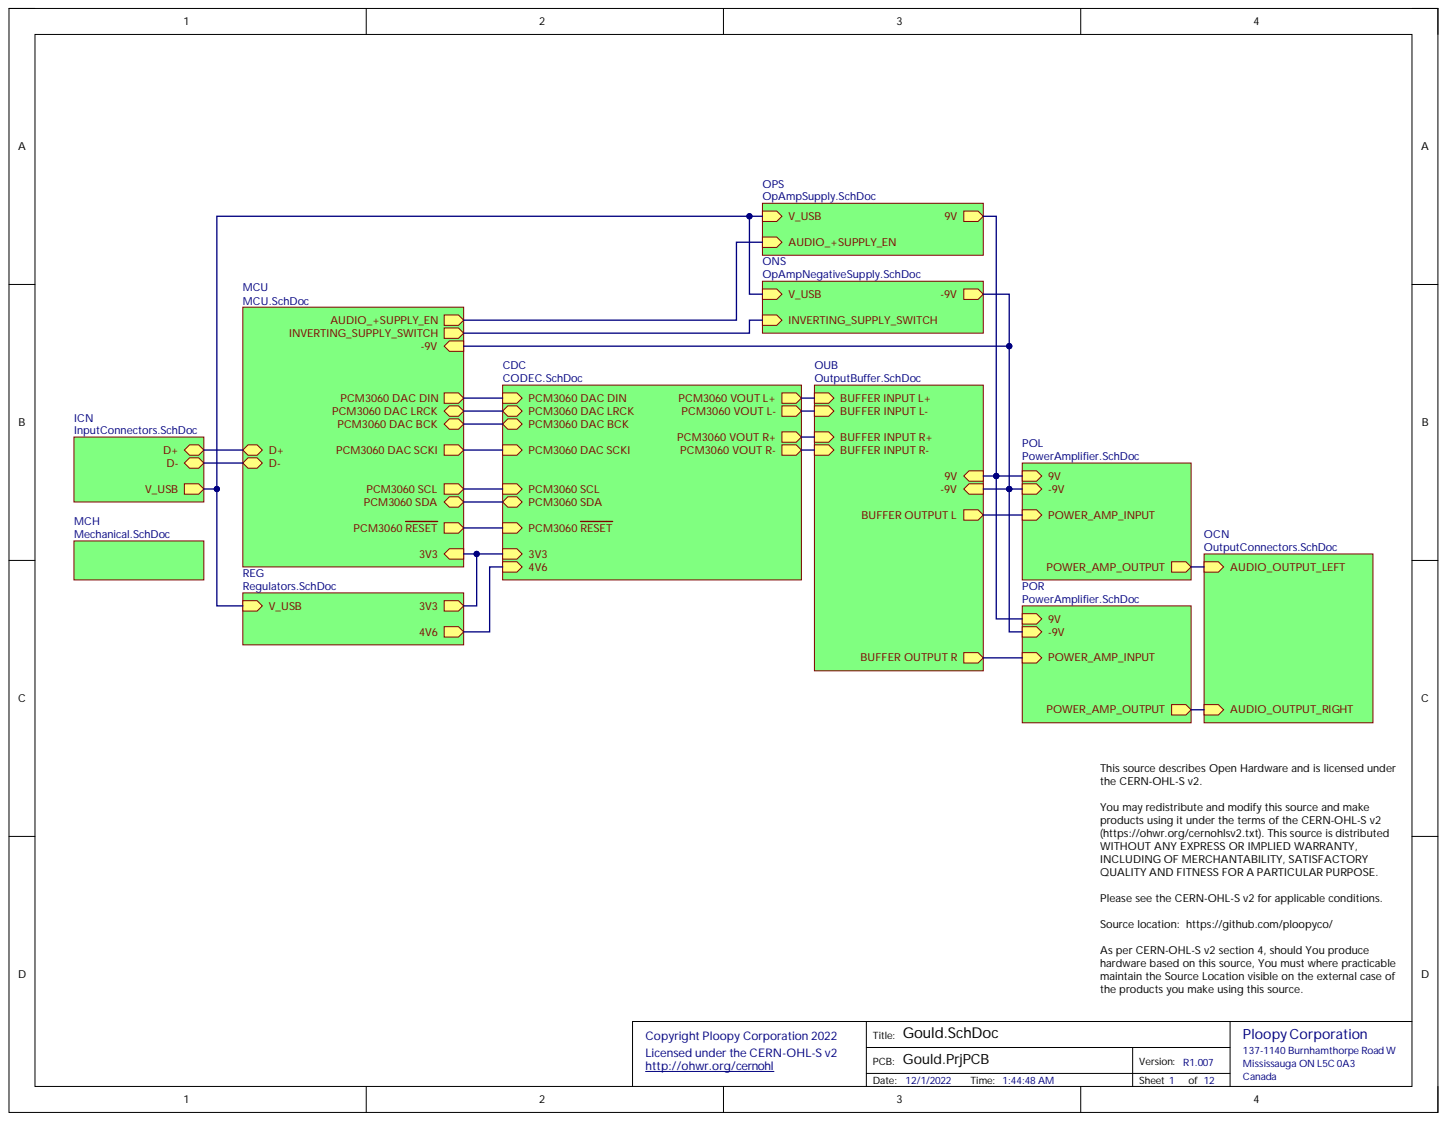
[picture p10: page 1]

This source describes Open Hardware and is licensed under
the CERN-OHL-S v2.

You may redistribute and modify this source and make
products using it under the terms of the CERN-OHL-S v2
(https://ohwr.org/cernohlsv2.txt). This source is distributed
WITHOUT ANY EXPRESS OR IMPLIED WARRANTY,
INCLUDING OF MERCHANTABILITY, SATISFACTORY
QUALITY AND FITNESS FOR A PARTICULAR PURPOSE.

Please see the CERN-OHL-S v2 for applicable conditions.

Source location: https://github.com/ploopyco/

As per CERN-OHL-S v2 section 4, should You produce
hardware based on this source, You must where practicable
maintain the Source Location visible on the external case of
the products you make using this source.

Copyright Ploopy Corporation 2022
Licensed under the CERN-OHL-S v2
http://ohwr.org/cernohl

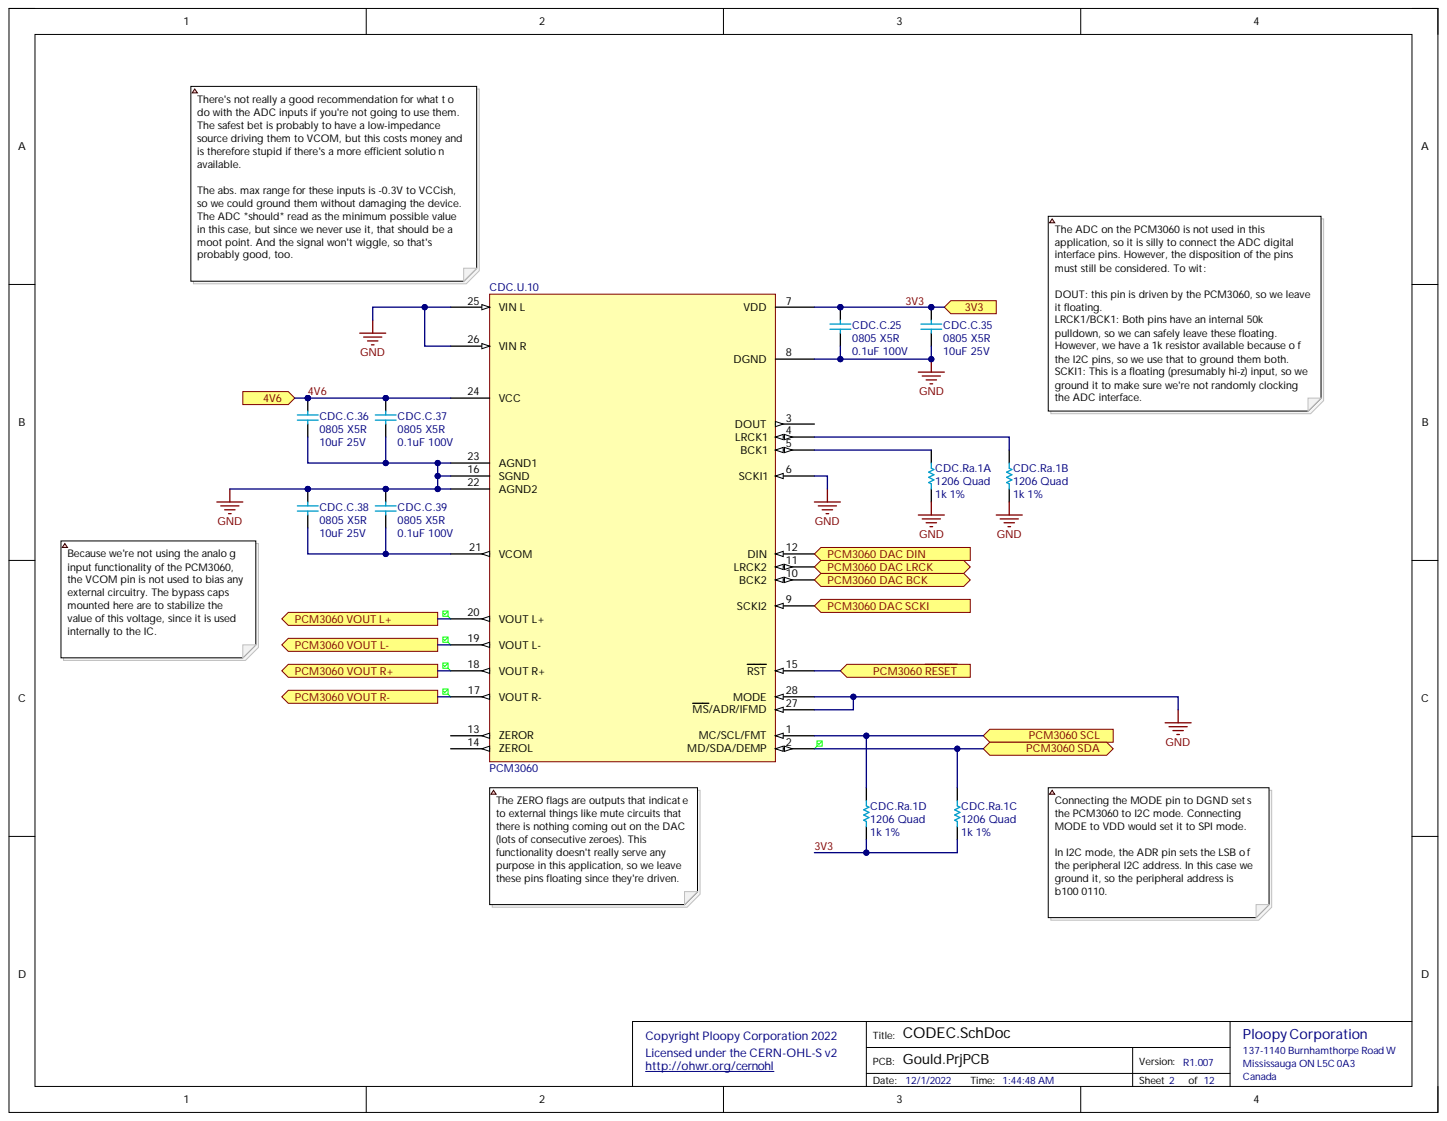
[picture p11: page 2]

There's not really a good recommendation for what to
do with the ADC inputs if you're not going to use them.
The safest bet is probably to have a low-impedance
source driving them to VCOM, but this costs money and
is therefore stupid if there's a more efficient solution
available.

The abs. max range for these inputs is -0.3V to VCCish,
so we could ground them without damaging the device.
The ADC *should* read as the minimum possible value
in this case, but since we never use it, that should be a
moot point. And the signal won't wiggle, so that's
probably good, too.

The ADC on the PCM3060 is not used in this
application, so it is silly to connect the ADC digital
interface pins. However, the disposition of the pins
must still be considered. To wit:

DOUT: this pin is driven by the PCM3060, so we leave
it floating.
LRCK1/BCK1: Both pins have an internal 50k
pulldown, so we can safely leave these floating.
However, we have a 1k resistor available because of
the I2C pins, so we use that to ground them both.
SCKI1: This is a floating (presumably hi-z) input, so we
ground it to make sure we're not randomly clocking
the ADC interface.

Because we're not using the analog
input functionality of the PCM3060,
the VCOM pin is not used to bias any
external circuitry. The bypass caps
mounted here are to stabilize the
value of this voltage, since it is used
internally to the IC.

The ZERO flags are outputs that indicate
to external things like mute circuits that
there is nothing coming out on the DAC
(lots of consecutive zeroes). This
functionality doesn't really serve any
purpose in this application, so we leave
these pins floating since they're driven.

Connecting the MODE pin to DGND sets
the PCM3060 to I2C mode. Connecting
MODE to VDD would set it to SPI mode.

In I2C mode, the ADR pin sets the LSB of
the peripheral I2C address. In this case we
ground it, so the peripheral address is

Copyright Ploopy Corporation 2022
Licensed under the CERN-OHL-S v2
http://ohwr.org/cernohl

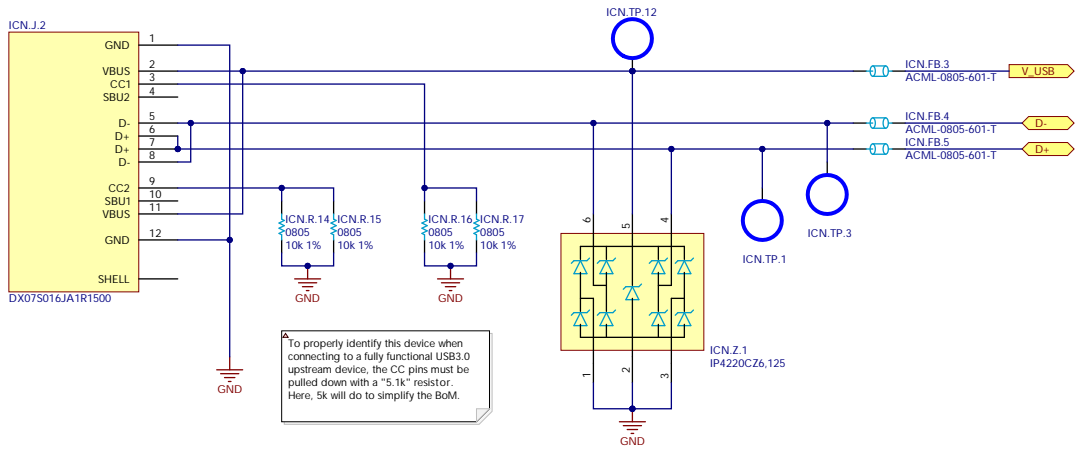
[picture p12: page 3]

Cop
Licensed under the CE
http

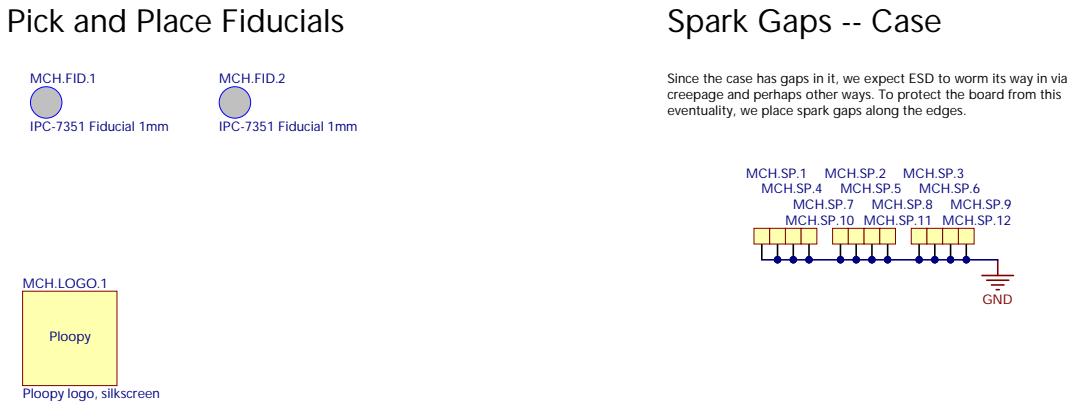
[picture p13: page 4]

Pick and Place Fiducials

Spark Gaps -- Case MCH.SP.1 MCH.SP.4 MCH.SP.10 MCH.SP.7 MCH.SP.2 MCH.SP.5 MCH.SP.11 MCH.SP.8 MCH.SP.

Since the case has gap
creepage and perhap
eventuality, we place s

s other ways. To protect the board from this
park gap

pect ESD to worm its way in via

Cop
Licensed under the CE
http

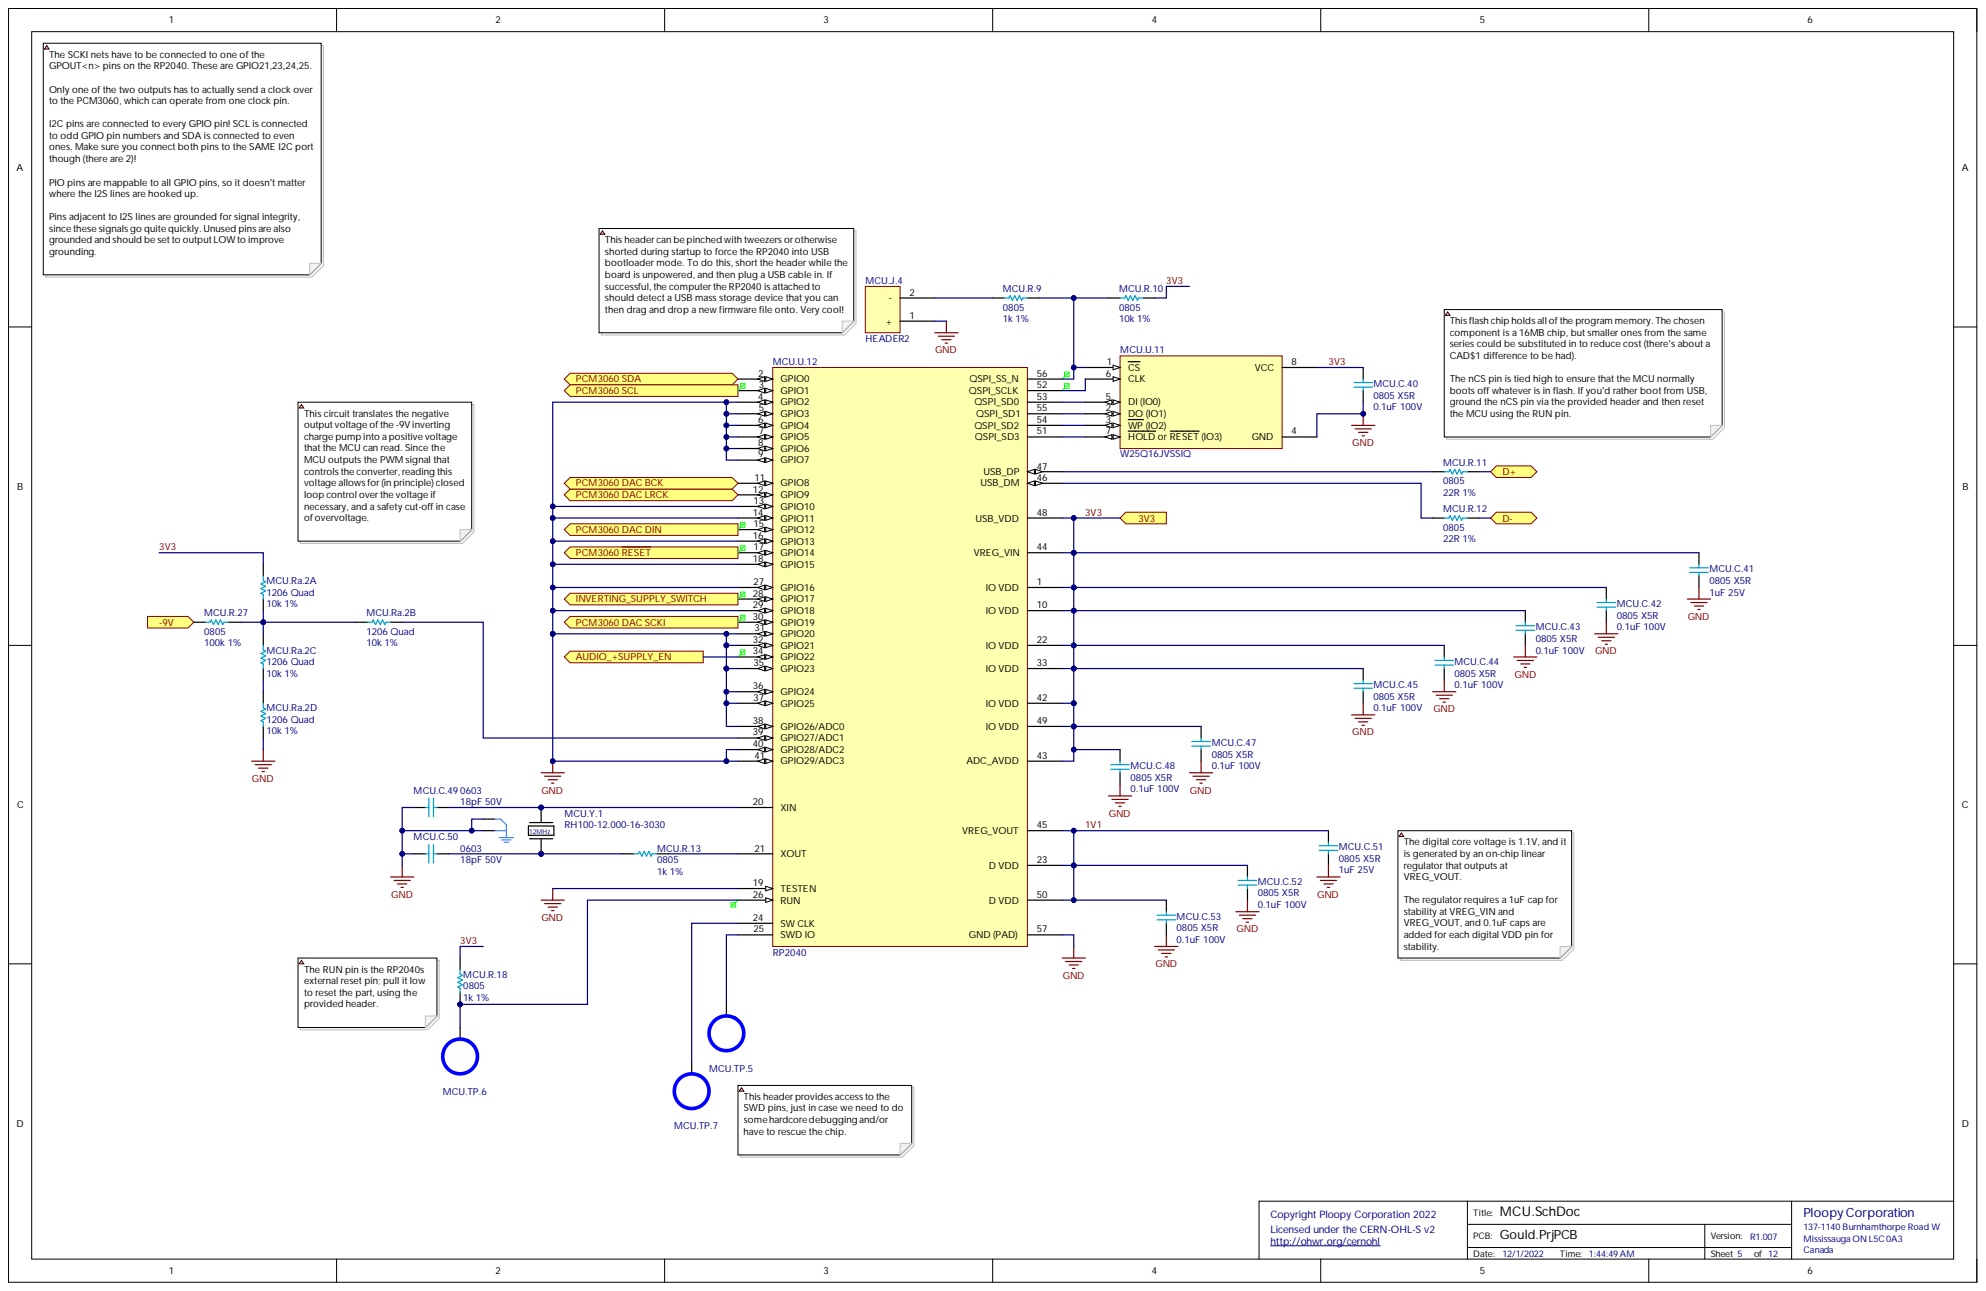
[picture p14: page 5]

The SCKI nets ha

Cop y rig h t Ploop y Cor pora tion 2 02 2 Lice n s e d u n d e r t h e CE R N -OH L -S v 2 h t t p : //ohwr .org /ce r noh l | T i t l e : MC U.S c h Doc | Plo opy C o rpo ra t i o n 1 3 7-1 1 40 B u r n h a m t hor p e Roa d W M i ssi ssa u g a O N L 5C 0A 3 C a n a d a

PC B : G o uld.P rjP C B | V e rsion : R 1 . 007

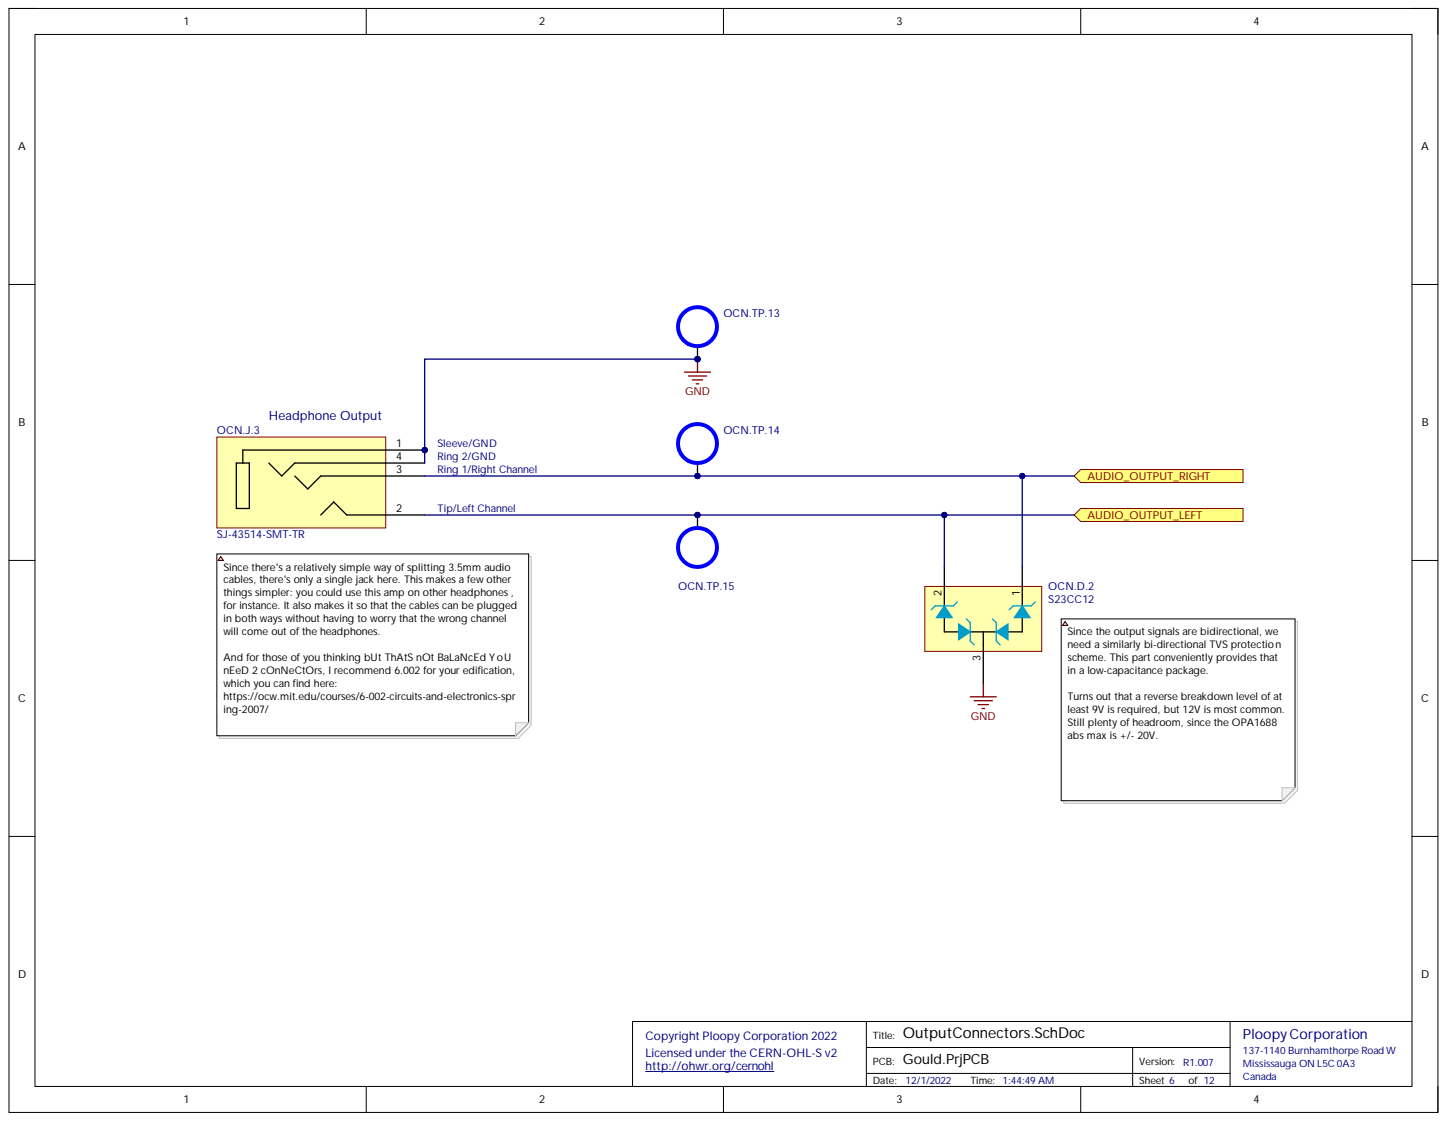
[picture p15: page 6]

Cop
Licensed under the CE
http

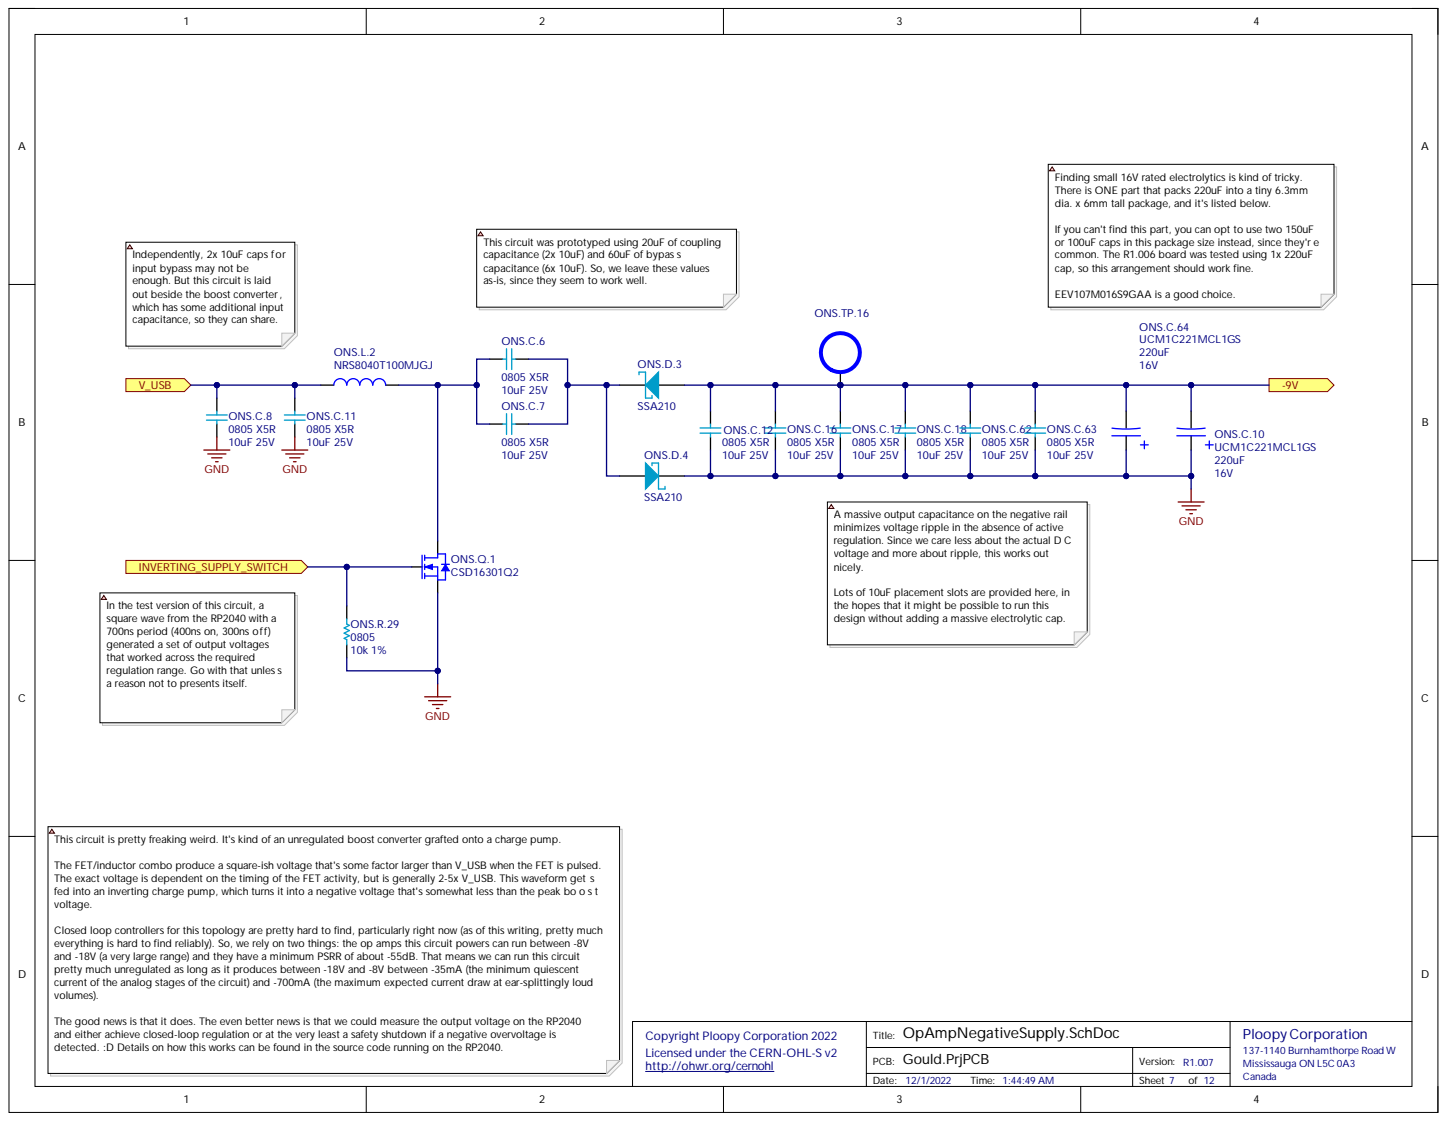
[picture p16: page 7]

Licensed under the CE
http

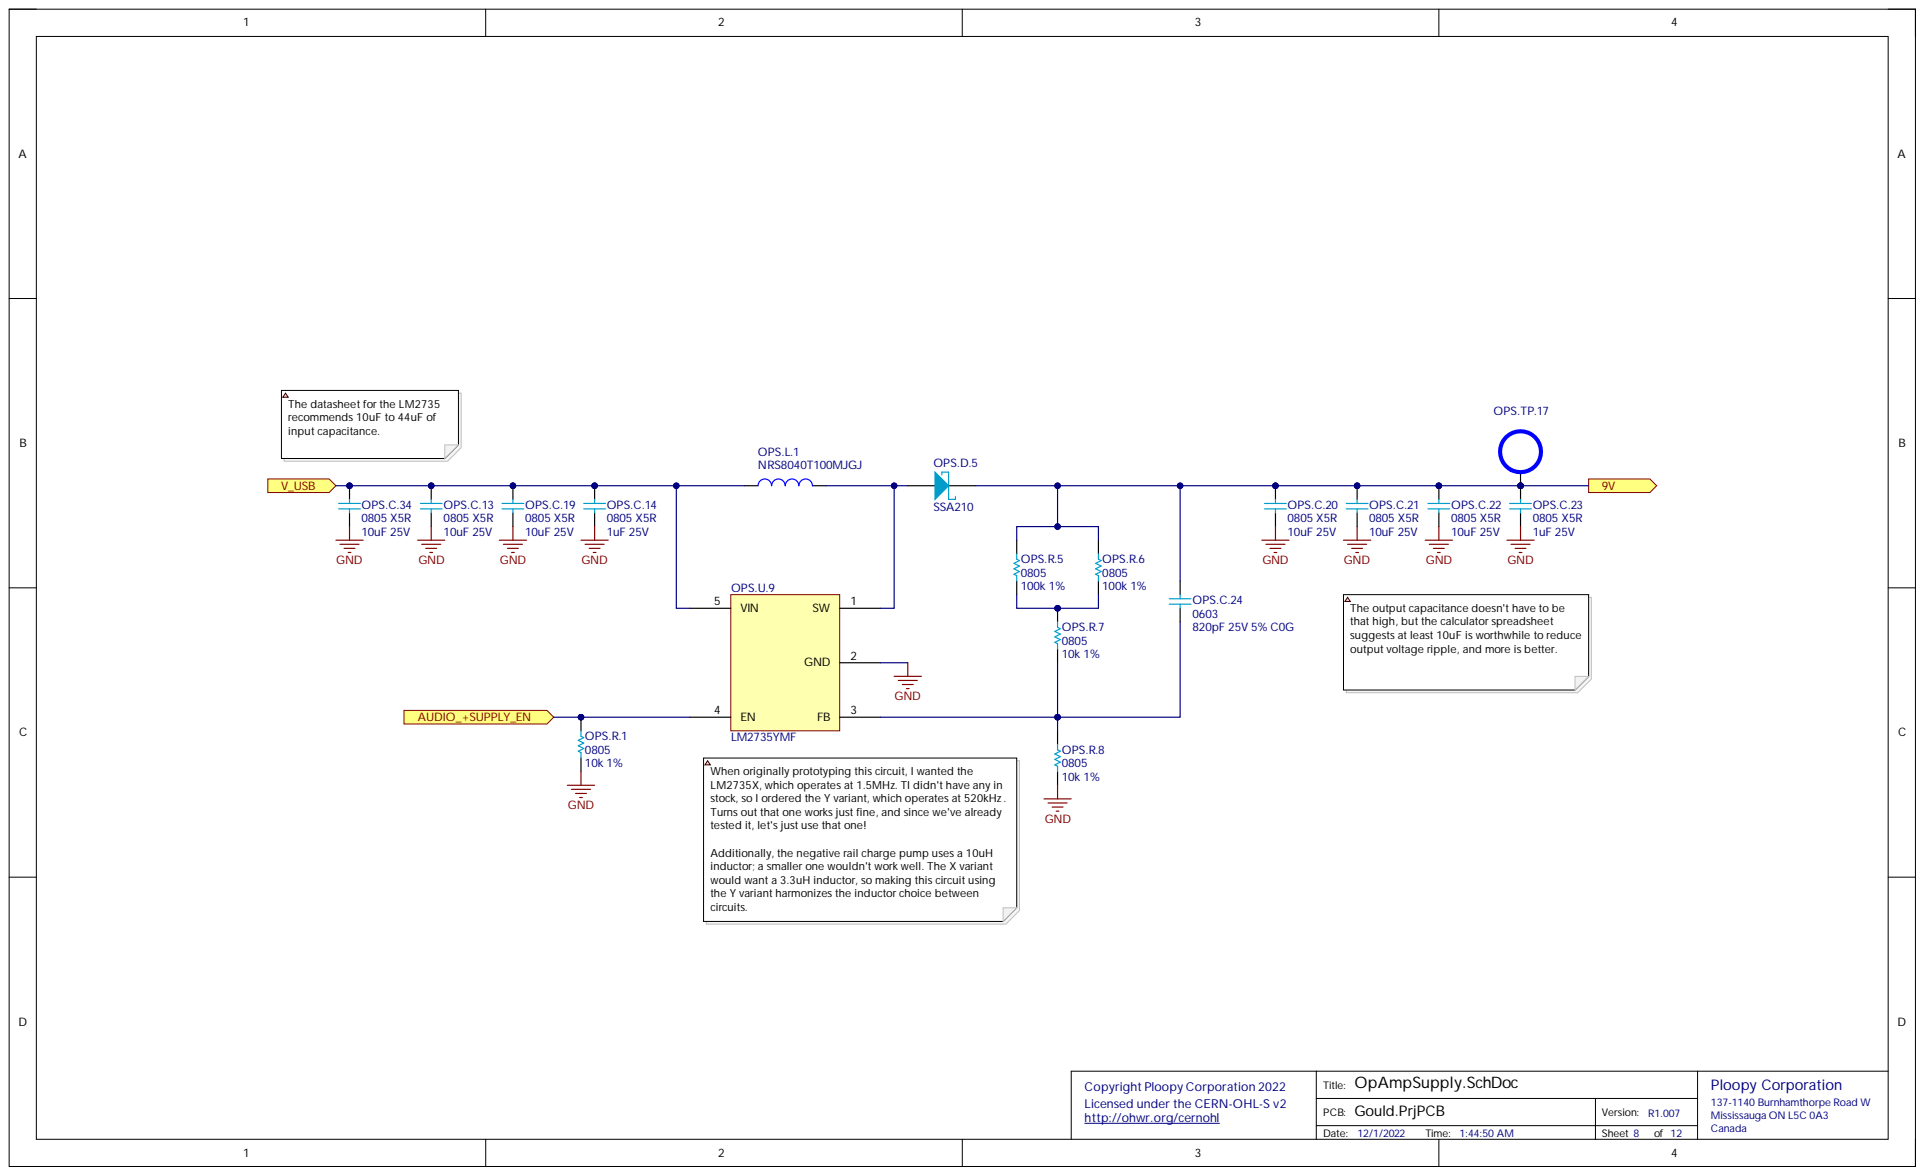
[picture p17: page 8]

100k 1% OPS.R.6 0805

C opy righ t Plo opy C o rpo ratio n 2 0 2 2 Lice n sed u nde r t h e CERN -O HL-S v 2 h t tp://o hwr.o rg/ce r n o h l | T i t le: O pAmpSup p l y .Sc h D o c | Ploop y Corporation 137-1140 Burnha m tho rpe Ro ad W M i ss i ssauga ON L5C 0A 3 C anada

Gould.PrjPC B P C B : | Vers i o n : R1.007

D a te: 12/1/2022 T i me: 1:44:50 A M | Sheet 8 o f 12

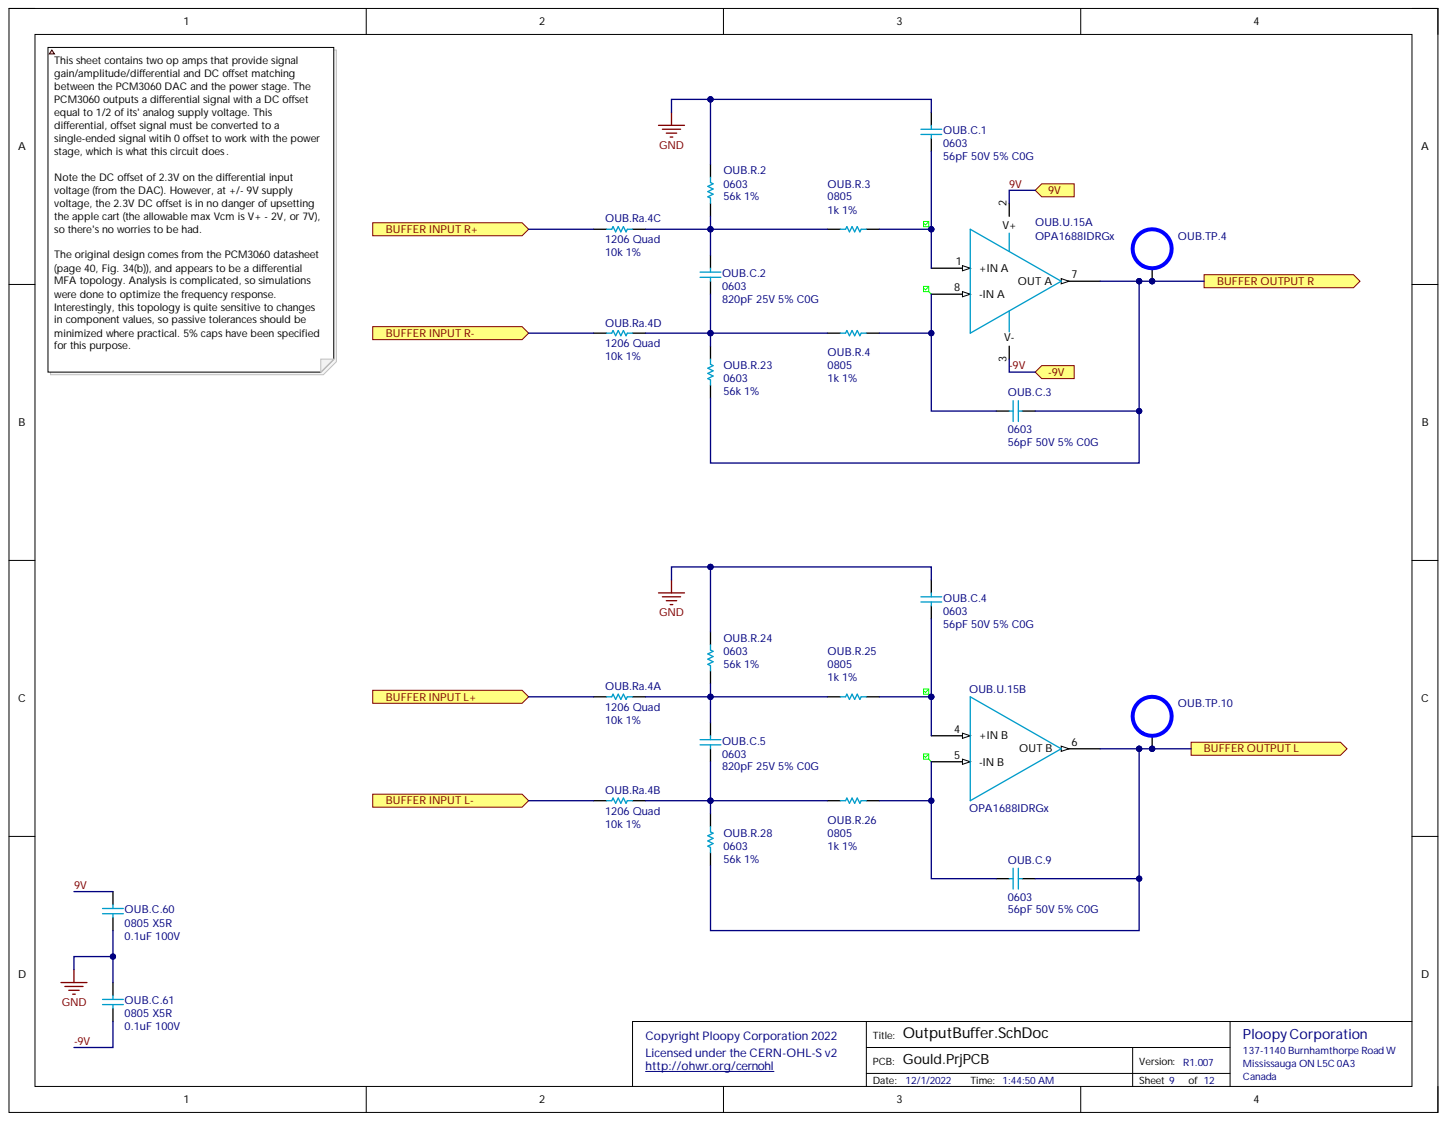
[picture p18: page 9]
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

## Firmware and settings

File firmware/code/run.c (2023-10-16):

/**
 * Copyright 2022 Colin Lam, Ploopy Corporation
 *
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
 * SPECIAL THANKS TO:
 * @kilograham (github.com/kilograham)
 * for his exceptional work on Pico Playground's usb-sound-card, on which
 * a large portion of this work is based.
 */

#include <math.h>
#include <stdlib.h>
#include <stdio.h>
#include <string.h>
#include <inttypes.h>

#include "hardware/vreg.h"
#include "hardware/pwm.h"
#include "hardware/i2c.h"
#include "hardware/sync.h"

#include "pico/stdlib.h"
#include "pico/usb_device.h"
#include "pico/usb_stream_helper.h"
#include "pico/multicore.h"
#include "pico/bootrom.h"
#include "pico/unique_id.h"
#include "AudioClassCommon.h"

#include "run.h"
#include "ringbuf.h"
#include "i2s.h"
#include "bqf.h"
#include "os_descriptors.h"
#include "configuration_manager.h"

i2s_obj_t i2s_write_obj;
static uint8_t *userbuf;

audio_state_config audio_state = {
    .freq = 48000,
    .de_emphasis_frequency = 0x1, // 48khz
    .interface = 0
};

preprocessing_config preprocessing = {
    .preamp = fix16_one,
    .postEQGain = fix16_one,
    .reverse_stereo = false
};

static char spi_serial_number[17] = "";

enum vendor_cmds {
    REBOOT_BOOTLOADER = 0,
    MICROSOFT_COMPATIBLE_ID_FEATURE_DESRIPTOR
};

int main(void) {
    setup();

    // Ask the configuration_manager to load a user config from flash,
    // or use the defaults.
    load_config();

    // start second core (called "core 1" in the SDK)
    multicore_launch_core1(core1_entry);
    multicore_fifo_push_blocking((uintptr_t) userbuf);
    uint32_t ready = multicore_fifo_pop_blocking();
    if (ready != CORE1_READY) {
        //printf("core 1 startup sequence is hella borked")
        exit(1);
    }

    usb_sound_card_init();

    while (true)
        __wfi();
}

static void update_volume()
{
    if (audio_state._volume != audio_state._target_volume) {
        // PCM3060 volume attenuation:
        //  0: 0db (default)
        //  55: -100db
        //  56..: Mute
        uint8_t buf[3];
        buf[0] = 65;    // register addr
        buf[1] = 255 + (audio_state.target_volume[0] / 128); // data left
        buf[2] = 255 + (audio_state.target_volume[1] / 128); // data right
        i2c_write_blocking(i2c0, PCM_I2C_ADDR, buf, 3, false);

        audio_state._volume = audio_state._target_volume;
    }

    if (audio_state.pcm3060_registers != audio_state._target_pcm3060_registers) {
        uint8_t buf[3];
        buf[0] = 68;    // register addr
        buf[1] = audio_state.target_pcm3060_registers[0]; // Reg 68
        buf[2] = audio_state.target_pcm3060_registers[1]; // Reg 69
        i2c_write_blocking(i2c0, PCM_I2C_ADDR, buf, 3, false);
        audio_state.pcm3060_registers = audio_state._target_pcm3060_registers;
    }
}

// Here's the meat. It's where the data buffer from USB gets transformed from
// PCM data into I2S data that gets shipped out to the PCM3060. It really
// belongs with the other USB-related code due to its utter indecipherability,
// but it's placed here to emphasize its importance.
static void __no_inline_not_in_flash_func(_as_audio_packet)(struct usb_endpoint *ep) {
    struct usb_buffer *usb_buffer = usb_current_out_packet_buffer(ep);
    int16_t *in = (int16_t *) usb_buffer->data;
    int32_t *out = (int32_t *) userbuf;
    int samples = usb_buffer->data_len / 2;

    // Make sure core 1 is ready for us.
    multicore_fifo_pop_blocking();

    if (save_config()) {
        // Skip processing while we are writing to flash
        multicore_fifo_push_blocking(CORE0_ABORTED);
        // keep on truckin'
        usb_grow_transfer(ep->current_transfer, 1);
        usb_packet_done(ep);
        return;
    }

    if (preprocessing.reverse_stereo) {
        for (int i = 0; i < samples; i+=2) {
            out[i] = in[i+1];
            out[i+1] = in[i];
        }
    }
    else {
        for (int i = 0; i < samples; i++)
            out[i] = in[i];
    }
 
    multicore_fifo_push_blocking(CORE0_READY);
    multicore_fifo_push_blocking(samples);


    // Left channel filter
    for (int i = 0; i < samples; i += 2) {
        fix3_28_t x_f16 = fix16_mul(norm_fix3_28_from_s16sample((int16_t) out[i]), preprocessing.preamp);
        for (int j = 0; j < filter_stages; j++) {
            x_f16 = bqf_transform(x_f16, &bqf_filters_left[j],
                &bqf_filters_mem_left[j]);
        }

        /* Apply post-EQ gain. */
        x_f16 = fix16_mul( x_f16, preprocessing.postEQGain);

        out[i] = (int32_t) norm_fix3_28_to_s16sample(x_f16);
    }

    // Block until core 1 has finished transforming the data
    uint32_t ready = multicore_fifo_pop_blocking();
    multicore_fifo_push_blocking(CORE0_READY);

    // Update the volume if required. We do this from core1 as
    // core0 is more heavily loaded, doing this from core0 can
    // lead to audio crackling.
    update_volume();

    // Update filters if required
    apply_config_changes();

    // keep on truckin'
    usb_grow_transfer(ep->current_transfer, 1);
    usb_packet_done(ep);
}

void __no_inline_not_in_flash_func(core1_entry)() {
    uint8_t *userbuf = (uint8_t *) multicore_fifo_pop_blocking();
    int32_t *out = (int32_t *) userbuf;

    // Signal that the thread has started
    multicore_fifo_push_blocking(CORE1_READY);

    while (true) {
        // Signal to core 0 that we are ready to accept new data
        multicore_fifo_push_blocking(CORE1_READY);

        // Block until the userbuf is filled with data
        uint32_t ready = multicore_fifo_pop_blocking();
        if (ready == CORE0_ABORTED) continue;
        
        const uint32_t samples = multicore_fifo_pop_blocking();

        /* Right channel EQ. */
        for (int i = 1; i < samples; i += 2) {
            /* Apply EQ pre-filter gain to avoid clipping. */
            fix3_28_t x_f16 = fix16_mul(norm_fix3_28_from_s16sample((int16_t) out[i]), preprocessing.preamp);
            /* Apply the biquad filters one by one. */
            for (int j = 0; j < filter_stages; j++) {
                x_f16 = bqf_transform(x_f16, &bqf_filters_right[j],
                    &bqf_filters_mem_right[j]);
            }
            /* Apply post-EQ gain. */
            x_f16 = fix16_mul( x_f16, preprocessing.postEQGain);

            out[i] = (int32_t) norm_fix3_28_to_s16sample(x_f16);
        }

        // Signal to core 0 that the data has all been transformed
        multicore_fifo_push_blocking(CORE1_READY);

        // Wait for Core 0 to finish running its filtering before we apply config updates
        multicore_fifo_pop_blocking();

        i2s_stream_write(&i2s_write_obj, userbuf, samples * 4);
    }
}

void setup() {
    set_sys_clock_khz(SYSTEM_FREQ / 1000, true);
    sleep_ms(100);
    stdio_init_all();

    for (int i=0; i<MAX_FILTER_STAGES; i++) {
        bqf_memreset(&bqf_filters_mem_left[i]);
        bqf_memreset(&bqf_filters_mem_right[i]);
    }

    pico_get_unique_board_id_string(spi_serial_number, 17);
    descriptor_strings[2] = spi_serial_number;
    userbuf = malloc(sizeof(uint8_t) * RINGBUF_LEN_IN_BYTES);
    
    // Configure DAC PWM
    gpio_set_function(PCM3060_SCKI2_PIN, GPIO_FUNC_PWM);
    uint slice_num_dac = pwm_gpio_to_slice_num(PCM3060_SCKI2_PIN);
    uint chan_num_dac = pwm_gpio_to_channel(PCM3060_SCKI2_PIN);
    pwm_set_phase_correct(slice_num_dac, false);
    pwm_set_wrap(slice_num_dac, (SYSTEM_FREQ / CODEC_FREQ) - 1);
    pwm_set_chan_level(slice_num_dac, chan_num_dac, (SYSTEM_FREQ / CODEC_FREQ / 2));
    pwm_set_enabled(slice_num_dac, true);

    gpio_init(AUDIO_POS_SUPPLY_EN_PIN);
    gpio_set_dir(AUDIO_POS_SUPPLY_EN_PIN, GPIO_OUT);
    gpio_put(AUDIO_POS_SUPPLY_EN_PIN, true);

    sleep_ms(100);

    configure_neg_switch_pwm();

    // After negative switching PWM is configured, take the PCM out of reset
    gpio_init(PCM3060_RST_PIN);
    gpio_set_dir(PCM3060_RST_PIN, GPIO_OUT);
    gpio_put(PCM3060_RST_PIN, true);

    // The PCM3060 supports standard mode (100kbps) or fast mode (400kbps)
    // we run in fast mode so we dont block the core for too long while
    // updating the volume.
    i2c_init(i2c0, 400000);
    gpio_set_function(PCM3060_SDA_PIN, GPIO_FUNC_I2C);
    gpio_set_function(PCM3060_SCL_PIN, GPIO_FUNC_I2C);
    gpio_pull_up(PCM3060_SDA_PIN);
    gpio_pull_up(PCM3060_SCL_PIN);

    // Let the PCM stabilize before power-on
    sleep_ms(200);

    // Resynchronise clocks. Do not enable PCM yet.
    uint8_t buf[2];
    buf[0] = 64; // register addr
    buf[1] = 0xB0; // data
    i2c_write_blocking(i2c0, PCM_I2C_ADDR, buf, 2, false);

    // Don't remove this. Don't do it.
    sleep_ms(200);

    // Enable DAC
    buf[0] = 64; // register addr
    buf[1] = 0xE0; // data
    i2c_write_blocking(i2c0, PCM_I2C_ADDR, buf, 2, false);

    // Same here, pal. Hands off.
    sleep_ms(100);

    // Set data format to 24 bit right justified, MSB first
    buf[0] = 67;   // register addr
    buf[1] = 0x02; // data
    i2c_write_blocking(i2c0, PCM_I2C_ADDR, buf, 2, false);

    i2s_write_obj.sck_pin = PCM3060_DAC_SCK_PIN;
    i2s_write_obj.ws_pin = PCM3060_DAC_WS_PIN;
    i2s_write_obj.sd_pin = PCM3060_DAC_SD_PIN;
    i2s_write_obj.sampling_rate = SAMPLING_FREQ;

    i2s_write_init(&i2s_write_obj);
}

/** **************************************************************************
 * DO. NOT. FUCKING. CHANGE. THIS. FUNCTION.                                 *
 * IF YOU DO, YOU COULD BLOW UP YOUR HARDWARE!                               *
 * YOU WERE WARNED!!!!!!!!!!!!!!!!                                           *
 ****************************************************************************/
 // TODO: roundf will be much faster than round, but it might mess with timings
void configure_neg_switch_pwm() {
    gpio_set_function(NEG_SWITCH_PWM_PIN, GPIO_FUNC_PWM);
    uint slice_num = pwm_gpio_to_slice_num(NEG_SWITCH_PWM_PIN);
    uint chan_num = pwm_gpio_to_channel(NEG_SWITCH_PWM_PIN);
    pwm_set_phase_correct(slice_num, false);

    uint16_t wrap = round((float) SYSTEM_FREQ / (float) NEG_SWITCH_FREQ);
    pwm_set_wrap(slice_num, wrap - 1);

    uint16_t target_level = round((float) SYSTEM_FREQ / (float) NEG_SWITCH_FREQ /
            (float) NEG_DUTY_DEN * (float) NEG_DUTY_NUM);
    pwm_set_chan_level(slice_num, chan_num, 0);
    pwm_set_enabled(slice_num, true);
    sleep_ms(10);

    // Ramp up the duty cycle.
    // Seriously, don't fuck with this. A spike on the negative voltage supply
    // because this isn't ramping correctly will destroy the hardware.
    size_t i;
    for(i = 0; i < 200; i++) {
        uint16_t current_level = round(i * ((float)target_level / 200.0));
        pwm_set_chan_level(slice_num, chan_num, current_level);
        sleep_ms(1);
    }
}




/*****************************************************************************
 * USB-related code begins here. It's a refactoring nightmare, so here it
 * shall lie for a thousand years.
 ****************************************************************************/

// todo noop when muted

static const audio_device_config ad_conf = {
    .descriptor = {
        .bLength = sizeof(ad_conf.descriptor),
        .bDescriptorType = DTYPE_Configuration,
        .wTotalLength = sizeof(ad_conf),
        .bNumInterfaces = 3,
        .bConfigurationValue = 0x01,
        .iConfiguration = 0x00,
        .bmAttributes = 0x80,
        .bMaxPower = 0xFA,
    },
    .ac_interface = {
        .bLength = sizeof(ad_conf.ac_interface),
        .bDescriptorType = DTYPE_Interface,
        .bInterfaceNumber = 0x00,
        .bAlternateSetting = 0x00,
        .bNumEndpoints = 0x00,
        .bInterfaceClass = AUDIO_CSCP_AudioClass,
        .bInterfaceSubClass = AUDIO_CSCP_ControlSubclass,
        .bInterfaceProtocol = AUDIO_CSCP_ControlProtocol,
        .iInterface = 0x00,
    },
    .ac_audio = {
        .core = {
            .bLength = sizeof(ad_conf.ac_audio.core),
            .bDescriptorType = AUDIO_DTYPE_CSInterface,
            .bDescriptorSubtype = AUDIO_DSUBTYPE_CSInterface_Header,
            .bcdADC = VERSION_BCD(1, 0, 0),
            .wTotalLength = sizeof(ad_conf.ac_audio),
            .bInCollection = 1,
            .bInterfaceNumbers = 1,
        },
        .input_terminal = {
            .bLength = sizeof(ad_conf.ac_audio.input_terminal),
            .bDescriptorType = AUDIO_DTYPE_CSInterface,
            .bDescriptorSubtype = AUDIO_DSUBTYPE_CSInterface_InputTerminal,
            .bTerminalID = 1,
            .wTerminalType = AUDIO_TERMINAL_STREAMING,
            .bAssocTerminal = 0,
            .bNrChannels = 2,
            .wChannelConfig = AUDIO_CHANNEL_LEFT_FRONT | AUDIO_CHANNEL_RIGHT_FRONT,
            .iChannelNames = 0,
            .iTerminal = 0,
        },
        .feature_unit = {
            .bLength = sizeof(ad_conf.ac_audio.feature_unit),
            .bDescriptorType = AUDIO_DTYPE_CSInterface,
            .bDescriptorSubtype = AUDIO_DSUBTYPE_CSInterface_Feature,
            .bUnitID = 2,
            .bSourceID = 1,
            .bControlSize = 1,
            .bmaControls = {
                AUDIO_FEATURE_MUTE, // Master channel
                AUDIO_FEATURE_VOLUME, // Left channel
                AUDIO_FEATURE_VOLUME, // Right channel
            },
            .iFeature = 0,
        },
        .output_terminal = {
            .bLength = sizeof(ad_conf.ac_audio.output_terminal),
            .bDescriptorType = AUDIO_DTYPE_CSInterface,
            .bDescriptorSubtype = AUDIO_DSUBTYPE_CSInterface_OutputTerminal,
            .bTerminalID = 3,
            .wTerminalType = AUDIO_TERMINAL_OUT_HEADPHONES,
            .bAssocTerminal = 0,
            .bSourceID = 2,
            .iTerminal = 0,
        },
    },
    .as_zero_interface = {
        .bLength = sizeof(ad_conf.as_zero_interface),
        .bDescriptorType = DTYPE_Interface,
        .bInterfaceNumber = 0x01,
        .bAlternateSetting = 0x00,
        .bNumEndpoints = 0x00,
        .bInterfaceClass = AUDIO_CSCP_AudioClass,
        .bInterfaceSubClass = AUDIO_CSCP_AudioStreamingSubclass,
        .bInterfaceProtocol = AUDIO_CSCP_ControlProtocol,
        .iInterface = 0x00,
    },
    .as_op_interface = {
        .bLength = sizeof(ad_conf.as_op_interface),
        .bDescriptorType = DTYPE_Interface,
        .bInterfaceNumber = 0x01,
        .bAlternateSetting = 0x01,
        .bNumEndpoints = 0x02,
        .bInterfaceClass = AUDIO_CSCP_AudioClass,
        .bInterfaceSubClass = AUDIO_CSCP_AudioStreamingSubclass,
        .bInterfaceProtocol = AUDIO_CSCP_ControlProtocol,
        .iInterface = 0x00,
    },
    .as_audio = {
        .streaming = {
            .bLength = sizeof(ad_conf.as_audio.streaming),
            .bDescriptorType = AUDIO_DTYPE_CSInterface,
            .bDescriptorSubtype = AUDIO_DSUBTYPE_CSInterface_General,
            .bTerminalLink = 1,
            .bDelay = 1,
            .wFormatTag = 1, // PCM
        },
        .format = {
            .core = {
                .bLength = sizeof(ad_conf.as_audio.format),
                .bDescriptorType = AUDIO_DTYPE_CSInterface,
                .bDescriptorSubtype = AUDIO_DSUBTYPE_CSInterface_FormatType,
                .bFormatType = 1,
                .bNrChannels = 2,
                .bSubFrameSize = 2,
                .bBitResolution = 16,
                .bSampleFrequencyType = 1,
            },
            .freqs = {
                0x80,
                0xBB,
                0x00
            },
        },
    },
    .ep1 = {
        .core = {
            .bLength = sizeof(ad_conf.ep1.core),
            .bDescriptorType = DTYPE_Endpoint,
            .bEndpointAddress = 0x01,
            .bmAttributes = 5,
            .wMaxPacketSize = (uint8_t) 0xC4,
            .bInterval = 1,
            .bRefresh = 0,
            .bSyncAddr = 0x82,
        },
        .audio = {
            .bLength = sizeof(ad_conf.ep1.audio),
            .bDescriptorType = AUDIO_DTYPE_CSEndpoint,
            .bDescriptorSubtype = AUDIO_DSUBTYPE_CSEndpoint_General,
            .bmAttributes = 1,
            .bLockDelayUnits = 0,
            .wLockDelay = 0,
        }
    },
    .ep2 = {
        .bLength = sizeof(ad_conf.ep2),
        .bDescriptorType = 0x05,
        .bEndpointAddress = 0x82,
        .bmAttributes = 0x11,
        .wMaxPacketSize = 3,
        .bInterval = 0x01,
        .bRefresh = 2,
        .bSyncAddr = 0,
    },
    .configuration_interface = {
        .bLength = sizeof(ad_conf.configuration_interface),
        .bDescriptorType = DTYPE_Interface,
        .bInterfaceNumber = 0x02,
        .bAlternateSetting = 0x00,
        .bNumEndpoints = 0x02,
        .bInterfaceClass = 0xff, // Vendor Specific
        .bInterfaceSubClass = 0,
        .bInterfaceProtocol = 0,
        .iInterface = 0x00
    },
    .ep3 = {
        .bLength = sizeof(ad_conf.ep3),
        .bDescriptorType = 0x05,
        .bEndpointAddress = 0x03,
        .bmAttributes = 0x2,
        .wMaxPacketSize = 0x40,
        .bInterval = 0x0
    },
    .ep4 = {
        .bLength = sizeof(ad_conf.ep3),
        .bDescriptorType = 0x05,
        .bEndpointAddress = 0x84,
        .bmAttributes = 0x2,
        .wMaxPacketSize = 0x40,
        .bInterval = 0x0
    }
};

static struct usb_interface ac_interface;
static struct usb_interface as_op_interface;
static struct usb_endpoint ep_op_out, ep_op_sync;
static struct usb_interface configuration_interface;
static struct usb_endpoint ep_configuration_in, ep_configuration_out;

static const struct usb_device_descriptor boot_device_descriptor = {
    .bLength            = 18,
    .bDescriptorType    = 0x01,
    .bcdUSB             = 0x0210,
    .bDeviceClass       = 0x00,
    .bDeviceSubClass    = 0x00,
    .bDeviceProtocol    = 0x00,
    .bMaxPacketSize0    = 0x40,
    .idVendor           = 0x2E8A,
    .idProduct          = 0xFEDD,
    .bcdDevice          = 0x0200,
    .iManufacturer      = 0x01,
    .iProduct           = 0x02,
    .iSerialNumber      = 0x03,
    .bNumConfigurations = 0x01,
};

const char *_get_descriptor_string(uint index) {
    if (index <= count_of(descriptor_strings)) {
        return descriptor_strings[index - 1];
    } else {
        return "";
    }
}

static void _as_sync_packet(struct usb_endpoint *ep) {
    assert(ep->current_transfer);
    struct usb_buffer *buffer = usb_current_in_packet_buffer(ep);
    assert(buffer->data_max >= 3);
    buffer->data_len = 3;

    ring_buf_t rb = i2s_write_obj.ring_buffer;
    uint32_t feedback;

    size_t lower_limit = (RINGBUF_LEN_IN_BYTES / 2) - (RINGBUF_LEN_IN_BYTES / 4);
    size_t upper_limit = (RINGBUF_LEN_IN_BYTES / 2) + (RINGBUF_LEN_IN_BYTES / 4);

    if (ringbuf_available_data(&rb) > upper_limit) {
        // slow down
        feedback = 47 << 14;
    } else if (ringbuf_available_data(&rb) < lower_limit) {
        // we need more data
        feedback = 49 << 14;
    } else
        feedback = 48 << 14;

    //double temp = rate * 0x00004000;
    //temp += (double)((temp >= 0) ? 0.5f : -0.5f);
    //uint32_t feedback = (uint32_t) temp;

    // todo lie thru our teeth for now
    //uint feedback = 48 << 14u;

    buffer->data[0] = feedback;
    buffer->data[1] = feedback >> 8u;
    buffer->data[2] = feedback >> 16u;

    // keep on truckin'
    usb_grow_transfer(ep->current_transfer, 1);
    usb_packet_done(ep);
}

static const struct usb_transfer_type as_transfer_type = {
    .on_packet = _as_audio_packet,
    .initial_packet_count = 1,
};

static const struct usb_transfer_type as_sync_transfer_type = {
    .on_packet = _as_sync_packet,
    .initial_packet_count = 1,
};

static struct usb_transfer as_transfer;
static struct usb_transfer as_sync_transfer;

static const struct usb_transfer_type config_in_transfer_type = {
    .on_packet = config_in_packet,
    .initial_packet_count = 1,
};

static const struct usb_transfer_type config_out_transfer_type = {
    .on_packet = config_out_packet,
    .on_cancel = configuration_ep_on_cancel,
    .initial_packet_count = 1,
};

static struct usb_transfer config_in_transfer;
static struct usb_transfer config_out_transfer;

static bool do_get_current(struct usb_setup_packet *setup) {
    if ((setup->bmRequestType & USB_REQ_TYPE_RECIPIENT_MASK) == USB_REQ_TYPE_RECIPIENT_INTERFACE) {
        switch (setup->wValue >> 8u) {
            case 1: { // mute
                usb_start_tiny_control_in_transfer((audio_state.mute != 0), 1);
                return true;
            }
            case 2: { // volume
                /* Current volume. See UAC Spec 1.0 p.77 */
                const uint8_t cn = (uint8_t) setup->wValue;
                if (cn == AUDIO_CHANNEL_LEFT_FRONT) {
                    usb_start_tiny_control_in_transfer(audio_state.target_volume[0], 2);
                }
                else if (cn == AUDIO_CHANNEL_RIGHT_FRONT) {
                    usb_start_tiny_control_in_transfer(audio_state.target_volume[1], 2);
                }
                else {
                    return false;
                }
                return true;
            }
        }
    } else if ((setup->bmRequestType & USB_REQ_TYPE_RECIPIENT_MASK) == USB_REQ_TYPE_RECIPIENT_ENDPOINT) {
        if ((setup->wValue >> 8u) == 1) { // endpoint frequency control
            /* Current frequency */
            usb_start_tiny_control_in_transfer(audio_state.freq, 3);
            return true;
        }
    }
    return false;
}

static bool do_get_minimum(struct usb_setup_packet *setup) {
    if ((setup->bmRequestType & USB_REQ_TYPE_RECIPIENT_MASK) == USB_REQ_TYPE_RECIPIENT_INTERFACE) {
        switch (setup->wValue >> 8u) {
            case 2: { // volume
                usb_start_tiny_control_in_transfer(MIN_VOLUME, 2);
                return true;
            }
        }
    }
    return false;
}
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

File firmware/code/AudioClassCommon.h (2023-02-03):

/*
             LUFA Library
     Copyright (C) Dean Camera, 2020.

  dean [at] fourwalledcubicle [dot] com
           www.lufa-lib.org
*/

/*
  Copyright 2020  Dean Camera (dean [at] fourwalledcubicle [dot] com)

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
  The author disclaims all warranties with regard to this
  software, including all implied warranties of merchantability
  and fitness.  In no event shall the author be liable for any
  special, indirect or consequential damages or any damages
  whatsoever resulting from loss of use, data or profits, whether
  in an action of contract, negligence or other tortious action,
  arising out of or in connection with the use or performance of
  this software.
*/

/** \file
 *  \brief Common definitions and declarations for the library USB Audio 1.0 Class driver.
 *
 *  Common definitions and declarations for the library USB Audio 1.0 Class driver.
 *
 *  \note This file should not be included directly. It is automatically included as needed by the USB module driver
 *        dispatch header located in LUFA/Drivers/USB.h.
 */

/** \ingroup Group_USBClassAudio
 *  \defgroup Group_USBClassAudioCommon  Common Class Definitions
 *
 *  \section Sec_USBClassAudioCommon_ModDescription Module Description
 *  Constants, Types and Enum definitions that are common to both Device and Host modes for the USB
 *  Audio 1.0 Class.
 *
 *  @{
 */

#ifndef _AUDIO_CLASS_COMMON_H_
#define _AUDIO_CLASS_COMMON_H_

/* Includes: */
#include "StdDescriptors.h"

/* Enable C linkage for C++ Compilers: */
#if defined(__cplusplus)
extern "C" {
#endif

/* Macros: */
/** \name Audio Channel Masks */
/**@{*/
/** Supported channel mask for an Audio class terminal descriptor. See the Audio class specification for more details. */
#define AUDIO_CHANNEL_LEFT_FRONT           (1 << 0)

/** Supported channel mask for an Audio class terminal descriptor. See the Audio class specification for more details. */
#define AUDIO_CHANNEL_RIGHT_FRONT          (1 << 1)

/** Supported channel mask for an Audio class terminal descriptor. See the Audio class specification for more details. */
#define AUDIO_CHANNEL_CENTER_FRONT         (1 << 2)

/** Supported channel mask for an Audio class terminal descriptor. See the Audio class specification for more details. */
#define AUDIO_CHANNEL_LOW_FREQ_ENHANCE     (1 << 3)

/** Supported channel mask for an Audio class terminal descriptor. See the Audio class specification for more details. */
#define AUDIO_CHANNEL_LEFT_SURROUND        (1 << 4)

/** Supported channel mask for an Audio class terminal descriptor. See the Audio class specification for more details. */
#define AUDIO_CHANNEL_RIGHT_SURROUND       (1 << 5)

/** Supported channel mask for an Audio class terminal descriptor. See the Audio class specification for more details. */
#define AUDIO_CHANNEL_LEFT_OF_CENTER       (1 << 6)

/** Supported channel mask for an Audio class terminal descriptor. See the Audio class specification for more details. */
#define AUDIO_CHANNEL_RIGHT_OF_CENTER      (1 << 7)

/** Supported channel mask for an Audio class terminal descriptor. See the Audio class specification for more details. */
#define AUDIO_CHANNEL_SURROUND             (1 << 8)

/** Supported channel mask for an Audio class terminal descriptor. See the Audio class specification for more details. */
#define AUDIO_CHANNEL_SIDE_LEFT            (1 << 9)

/** Supported channel mask for an Audio class terminal descriptor. See the Audio class specification for more details. */
#define AUDIO_CHANNEL_SIDE_RIGHT           (1 << 10)

/** Supported channel mask for an Audio class terminal descriptor. See the Audio class specification for more details. */
#define AUDIO_CHANNEL_TOP                  (1 << 11)
/**@}*/

/** \name Audio Feature Masks */
/**@{*/
/** Supported feature mask for an Audio class feature unit descriptor. See the Audio class specification for more details. */
#define AUDIO_FEATURE_MUTE                 (1 << 0)

/** Supported feature mask for an Audio class feature unit descriptor. See the Audio class specification for more details. */
#define AUDIO_FEATURE_VOLUME               (1 << 1)

/** Supported feature mask for an Audio class feature unit descriptor. See the Audio class specification for more details. */
#define AUDIO_FEATURE_BASS                 (1 << 2)

/** Supported feature mask for an Audio class feature unit descriptor. See the Audio class specification for more details. */
#define AUDIO_FEATURE_MID                  (1 << 3)

/** Supported feature mask for an Audio class feature unit descriptor. See the Audio class specification for more details. */
#define AUDIO_FEATURE_TREBLE               (1 << 4)

/** Supported feature mask for an Audio class feature unit descriptor. See the Audio class specification for more details. */
#define AUDIO_FEATURE_GRAPHIC_EQUALIZER    (1 << 5)

/** Supported feature mask for an Audio class feature unit descriptor. See the Audio class specification for more details. */
#define AUDIO_FEATURE_AUTOMATIC_GAIN       (1 << 6)

/** Supported feature mask for an Audio class feature unit descriptor. See the Audio class specification for more details. */
#define AUDIO_FEATURE_DELAY                (1 << 7)

/** Supported feature mask for an Audio class feature unit descriptor. See the Audio class specification for more details. */
#define AUDIO_FEATURE_BASS_BOOST           (1 << 8)

/** Supported feature mask for an Audio class feature unit descriptor. See the Audio class specification for more details. */
#define AUDIO_FEATURE_BASS_LOUDNESS        (1 << 9)
/**@}*/

/** \name Audio Terminal Types */
/**@{*/
/** Terminal type constant for an Audio class terminal descriptor. See the Audio class specification for more details. */
#define AUDIO_TERMINAL_UNDEFINED           0x0100

/** Terminal type constant for an Audio class terminal descriptor. See the Audio class specification for more details. */
#define AUDIO_TERMINAL_STREAMING           0x0101

/** Terminal type constant for an Audio class terminal descriptor. See the Audio class specification for more details. */
#define AUDIO_TERMINAL_VENDOR              0x01FF

/** Terminal type constant for an Audio class terminal descriptor. See the Audio class specification for more details. */
#define AUDIO_TERMINAL_IN_UNDEFINED        0x0200

/** Terminal type constant for an Audio class terminal descriptor. See the Audio class specification for more details. */
#define AUDIO_TERMINAL_IN_MIC              0x0201

/** Terminal type constant for an Audio class terminal descriptor. See the Audio class specification for more details. */
#define AUDIO_TERMINAL_IN_DESKTOP_MIC      0x0202

/** Terminal type constant for an Audio class terminal descriptor. See the Audio class specification for more details. */
#define AUDIO_TERMINAL_IN_PERSONAL_MIC     0x0203

/** Terminal type constant for an Audio class terminal descriptor. See the Audio class specification for more details. */
#define AUDIO_TERMINAL_IN_OMNIDIR_MIC      0x0204
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

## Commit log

2023-02-03 firmware, mechanicals
    [PloopyPreampCase-RevA.STEP, PloopyPreampCase-RevA.STL]
2023-02-03 added electronics
    [Analog.PcbLib, Analog.SchLib, CODEC.SchDoc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]
2023-02-03 added dxfs
    [Earcup.DXF, HeadbandFoam.DXF, Membrane.DXF]
2023-02-08 Added gould schematic
2023-03-08 fixed digital distortion issue; uploaded new firmware
    [run.c]
2023-04-05 Fix audio distortion (#8)
    * Fix an overflow in the fix16_t usage which can lead to audio distortion.
    * Add a simple test application for running the filtering stages on a PC.
    * Fix readme typos.
    * Rename test to tools.
    * Remove volume multiplier
    ---------
    [run.c]
2023-04-13 Basic support for rebooting into the bootloader. (#10)
    [reboot_bootloader.py, run.c]
2023-07-14 Headphones toolbox (#18) (#19)
    * Initial, very incomplete, toolbox interface.
    * Refactored things to move ugly structs out of run.c. Experimental config structures.
    * Extra comments.
    * Continuted to implement communication protocol. Can now validate Filter Configuration Structures
    * Config save/load works.
    * Reverse stereo and preamp.
    * Fixes and minor features.
    * Codec confiuguration implementation.
    * Support sending configs back to the client.
    * Fix broken audio when changing a filter type.
    * Fix broken audio when changing a filter type.
    * Try to create a build workflow
    * Report version info
    * Disable interrupts while reconfiguring, reset all filters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
    [configuration_manager.h, configuration_types.h]
2023-07-19 Added new headband designs that come in 3 sizes and are more robust.
    [HPH-038-Headband-Round-LARGE.STEP, HPH-040-Headband-Square-MEDIUM.STEP, HPH-041-Headband-Triangle-SMALL.STEP]
2023-07-29 Updated the DAC case design files to revision OOO, which has a larger hole at the TRS jack output connector to accommodate cables with larger overmolds on the plug.
    [DAC-Case-NoLogo.STEP, PloopyPreampCase-RevA.STEP]
2023-08-15 - Replaced default EQ filter set with an 8-band EQ based on measurements from Oratory1990 and VSG (#21)
    - Default configuration reverses the left/right channels in the DAC, because the headphones are wired backwards (oopie!)
    [configuration_types.h]
2023-08-16 refactored volume updates and filter configs to run on core 1
2023-08-23 Enable oratory's 15 band EQ (#23)
    * Attempt at optimizing so the new filtering runs better.
    * Additional improvements.
    * Further optimisations.
    * Seems to work OK with 10 filters. Just noise with 11.
    * Increase config buffer size, and make the bqf_transform function inline
    * Remove extra loop and process input evently across both cores.
    * Enable 15 band EQ.
    * Shift some load of core1
    * Revert buffer size change
    * Mark USB transfer as done sooner.
    * Fast multiply.
    * Fix build failure.
    * Rollback changes we dont need.
    * Fix save config to flash
    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
    [configuration_types.h]
2023-09-14 Run the DAC in 24bit mode. (#25)
    * Run the DAC in 24bit mode.
    * Update comment.
    * Remove accidental paste
    * Fix distortion.
    * Shift up the samples into -1..1, not much different, but we get an extra bit of resolution at the low end.
    [run.c]
2023-09-14 Adjusted Oratory's default EQ: - Less bass. Excursion limits happen at 30-50Hz first, so reducing response in this range makes it a little less likely this will be a problem. Plus, I like it. - A lit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
    Updated config version to 4.
    Added a parameter for post EQ gain. Applied once after EQ is calculated.
    [configuration_types.h]
2023-10-16 Fix save config (#27)
    * Fix save config
    * Fix save config when no audio is playing
    * Fix build issue with the github workflow compiler
    [configuration_manager.h]

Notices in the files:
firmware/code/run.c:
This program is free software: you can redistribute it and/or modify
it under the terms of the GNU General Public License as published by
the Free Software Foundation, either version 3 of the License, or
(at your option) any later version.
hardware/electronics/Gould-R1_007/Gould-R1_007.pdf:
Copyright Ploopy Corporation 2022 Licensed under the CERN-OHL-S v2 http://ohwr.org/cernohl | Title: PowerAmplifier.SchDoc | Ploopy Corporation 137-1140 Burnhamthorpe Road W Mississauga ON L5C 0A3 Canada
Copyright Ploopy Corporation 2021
